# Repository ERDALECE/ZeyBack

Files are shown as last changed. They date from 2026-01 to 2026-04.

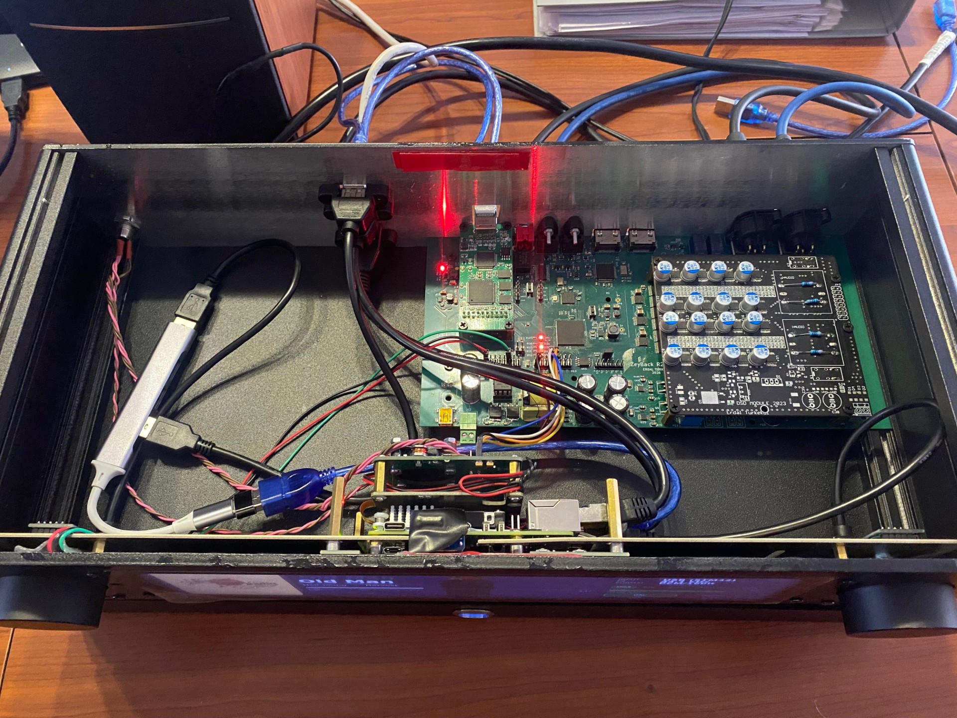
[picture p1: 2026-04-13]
Pictures/res5.jpg

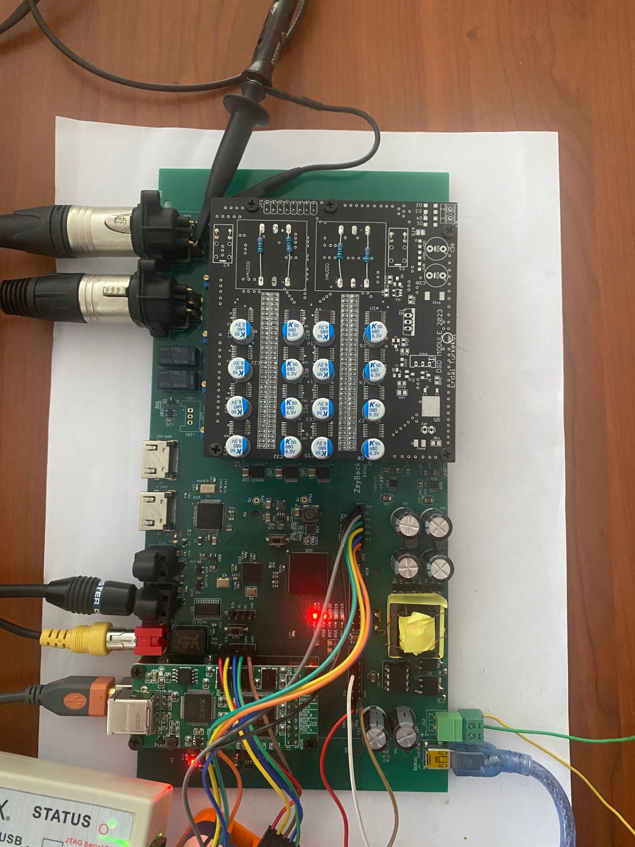
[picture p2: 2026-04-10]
Pictures/res1.jpg

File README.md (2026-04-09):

# ZeyBack R2RDAC

High-performance DIY USB Audio / FPGA based R-2R DAC platform.

The STM32H750 MCU plays audio in 44.1 kHz - 768 kHz PCM and DSD64 - DSD512 DSD (DoP) formats. 

Optionally, a second USB audio input can be added by connecting an XMOS or AMANERO.

SPDIF audio input up to 192 kHz is possible via the CS8416 or directly through the FPGA input.

It has one coaxial and two optical inputs.

HDMI audio input is possible with the ADV7611.

Direct I2S signal pins are also provided. An external I2S signal can also be supplied as an input through these pins.

With the SI5340, the reclocking operation is performed within the FPGA.

Input selection via infrared remote control is possible using the RC5 code. Debugging can be done via a separate USB COM port. 
Status information (sample rate, bitrate, selected input, etc.) is output as SPI from the FPGA.
MCUs, displays, etc., can be connected to SPI pins to display information via a GUI.

Main PCB is 6 Layer, DSD PCB is 4 Layer. 

All tests have been completed and no serious bugs have been found. However, it is open to improvement.

This repository contains:
- STM32H750 USB Audio Class 2.0 (UAC2) firmware (PCM + DSD related work)
- FPGA logic used for audio data path / clocking / I2S/DSD processing
- Hardware design files (KiCad schematics/PCB, BOM, Gerbers)

## Repository structure

- `Firmware/Stm32/`  
  STM32H750 project (STM32CubeIDE). Includes STM32Cube/HAL and middleware components.

- `Firmware/Fpga/`  
  FPGA project files (Vivado project + sources).

- `Hardware/`  
  KiCad project files, BOM/CSV, and manufacturing outputs (Gerbers).
  
- `Pictures/` 
  Some testing and pcb pictures.

## Build / Tools

- STM32: STM32CubeIDE (or gcc-arm + Make/CMake if you prefer)
- FPGA: Xilinx Vivado
- Hardware: KiCad

## DSD Native / Volumio notes

Goal: DSD Native playback on Linux (Volumio / Raspberry Pi) with proper USB descriptors and, if required,
a targeted `snd-usb-audio` quirk limited to this device (VID+PID).

## Licensing (IMPORTANT)

This repository is **multi-licensed**:

- **Firmware** (our original code): **GPL-3.0-or-later**
- **Hardware design files** (KiCad schematics/PCB): **CERN-OHL-S-2.0**
- **Documentation** (if/when added under `docs/`): **CC BY-SA 4.0**
- **Third-party components** (e.g., STM32Cube/HAL, middleware): keep their **original licenses**
  as stated in file headers and vendor license texts.

See:
- `LICENSE` (GPLv3 for the main project codebase)
- `Firmware/LICENSE` (firmware scope)
- `Hardware/LICENSE` (hardware scope)
- `THIRD_PARTY_NOTICES.md`

## Status

Work in progress....
Hardware design files in this directory (KiCad schematics/PCB and related design sources)
are licensed under CERN-OHL-S-2.0 (Strongly Reciprocal).

Manufacturing outputs (Gerbers) are provided for convenience.

See THIRD_PARTY_NOTICES.md for any third-party footprints/symbols (if applicable).

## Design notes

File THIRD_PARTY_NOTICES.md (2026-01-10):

# Third Party Notices

This repository may include third-party components such as:

## STM32Cube / ST HAL & Middleware
Files under `Firmware/Stm32/Drivers/` and parts of `Firmware/Stm32/Middlewares/` are provided by STMicroelectronics
and are distributed under their respective licenses.

- Do not remove or alter license headers in these files.
- These components remain under their original license terms.

## Other third-party content
If any additional third-party IP, HDL cores, footprints/symbols, or libraries are added,
they must retain their original license and be listed here.

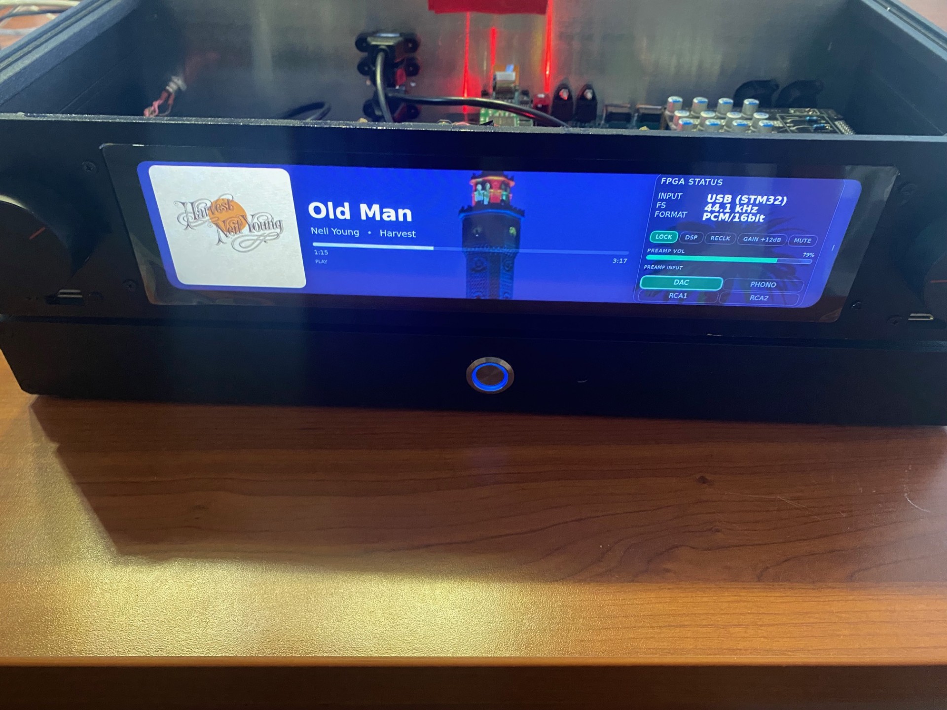
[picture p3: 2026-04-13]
Pictures/res4.jpg

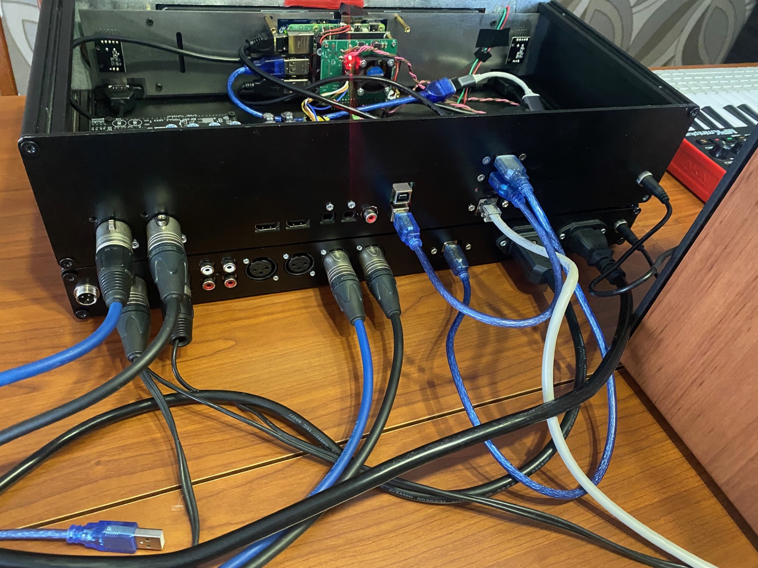
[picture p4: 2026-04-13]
Pictures/res8.jpg

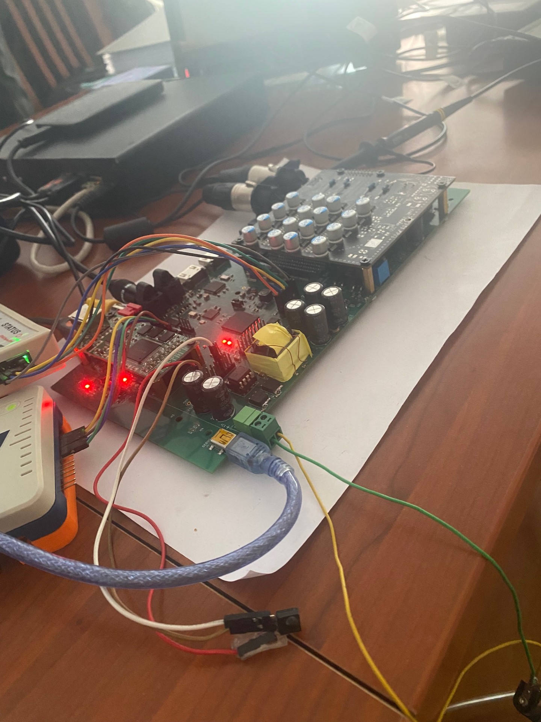
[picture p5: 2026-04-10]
Pictures/res2.jpg

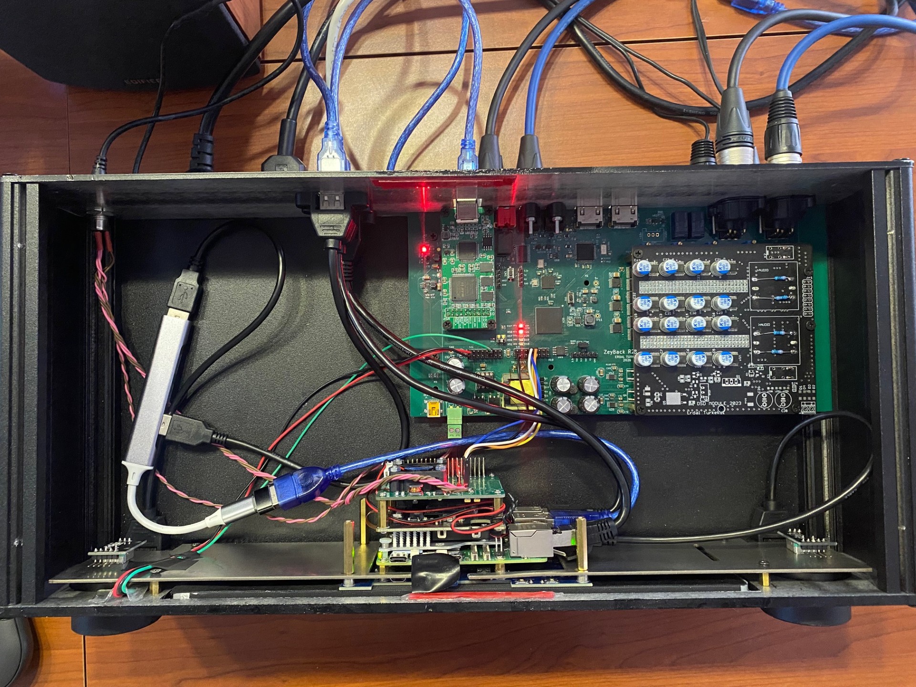
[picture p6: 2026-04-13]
Pictures/res6.jpg

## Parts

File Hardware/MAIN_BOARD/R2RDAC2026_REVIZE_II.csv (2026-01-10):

Source: | E:\KiCad Dosyalar\R2RDAC2025\R2RDAC2025.kicad_sch
Date: | Sun Feb 16 16:23:24 2025
Tool: | Eeschema 7.0.7
Generator: | C:\Program Files\KiCad\7.0\bin\scripting\plugins/bom_csv_grouped_by_value_with_fp.py
Component Count: | 797
Ref | Qnty | Value | Cmp name | Footprint | Description | Vendor | DNP
C1, C2, C3, C4, C5, C6, C8, C9, C10, C11, C14, C15, C16, C17, C18, C19, C20, C22, C40, C41, C42, C43, C44, C45, C46, C47, C48, C49, C50, C51, C76, C77, C78, C79, C119, C120, C166, C167, C170, C171, C172, C176, C177, C178, C179, C180, C181 | 47 | 100nf | C_0603 | XC7K325T_Footprint:C_0603_1608Metric | SMD 0603 MLCC capacitor, Alternate KiCad Library
C7, C23, C27, C29 | 4 | 10uf/6.3 | CP_SMD_Tantalum_Kemet-A_3216 | Capacitor_Tantalum_SMD:CP_EIA-3216-18_Kemet-A | SMD Tantalum Electrolytic Capacitor, Kemet Type A, 3216, US Symbol, Alternate KiCad Library
C12, C13 | 2 | 22pf | C_0603 | Capacitor_SMD:C_0603_1608Metric | SMD 0603 MLCC capacitor, Alternate KiCad Library
C21 | 1 | 1uf | C_0603 | XC7K325T_Footprint:C_0603_1608Metric | SMD 0603 MLCC capacitor, Alternate KiCad Library
C24, C75 | 2 | 10uF | C_0603 | PCM_Capacitor_SMD_AKL:C_0805_2012Metric | SMD 0603 MLCC capacitor, Alternate KiCad Library
C25, C34, C61, C62, C63, C185 | 6 | 100 nf | C_0603 | EP4CE_Footprint:C_0603_1608Metric | SMD 0603 MLCC capacitor, Alternate KiCad Library
C31, C32, C182, C183 | 4 | 4,7uF/16 | CP_SMD_Tantalum_Kemet-A_3216 | PCM_Capacitor_Tantalum_SMD_AKL:CP_EIA-3528-21_Kemet-B | SMD Tantalum Electrolytic Capacitor, Kemet Type A, 3216, European Symbol, Alternate KiCad Library
C33, C184 | 2 | 10 nf | C_0603 | EP4CE_Footprint:C_0603_1608Metric | SMD 0603 MLCC capacitor, Alternate KiCad Library
C35, C186 | 2 | 2,2nf | C_0603 | PCM_Capacitor_SMD_AKL:C_0603_1608Metric | SMD 0603 MLCC capacitor, Alternate KiCad Library
C36, C187 | 2 | 22pf | C_0603 | PCM_Capacitor_SMD_AKL:C_0603_1608Metric | SMD 0603 MLCC capacitor, Alternate KiCad Library
C37, C38, C188, C189 | 4 | 47uf/6.3 | CP_SMD_Tantalum_Kemet-B_3528 | PCM_Capacitor_Tantalum_SMD_AKL:CP_EIA-3216-18_Kemet-A | SMD Tantalum Electrolytic Capacitor, Kemet Type B, 3528, European Symbol, Alternate KiCad Library
C39, C190 | 2 | C_0603 | C_0603 | PCM_Capacitor_SMD_AKL:C_0603_1608Metric | SMD 0603 MLCC capacitor, Alternate KiCad Library
C52, C53 | 2 | CP_Radial_D8.0mm_P2.50mm | CP_Radial_D8.0mm_P2.50mm | PCM_Capacitor_THT_AKL:CP_Radial_D10.0mm_P7.50mm | THT Electrolytic Capacitor, 8.0mm Diameter, 2.50mm Pitch, European Symbol, Alternate KiCad Library
C54 | 1 | 470pf | C_0603 | PCM_Capacitor_SMD_AKL:C_0603_1608Metric | SMD 0603 MLCC capacitor, Alternate KiCad Library
C55, C56 | 2 | 10nf | C_0603 | PCM_Capacitor_SMD_AKL:C_0603_1608Metric | SMD 0603 MLCC capacitor, Alternate KiCad Library
C57, C58, C59, C60 | 4 | 1000uf/10v | CP_Radial_D8.0mm_P2.50mm | PCM_Capacitor_THT_AKL:CP_Radial_D10.0mm_P5.00mm | THT Electrolytic Capacitor, 8.0mm Diameter, 2.50mm Pitch, European Symbol, Alternate KiCad Library
C64, C65 | 2 | 47uf/10v | C_0603 | PCM_Capacitor_SMD_AKL:C_1210_3225Metric | SMD 0603 MLCC capacitor, Alternate KiCad Library
C66, C67, C70, C71 | 4 | 4.7uf | C_0603 | EP4CE_Footprint:C_0603_1608Metric | SMD 0603 MLCC capacitor, Alternate KiCad Library
C68, C69, C72, C73 | 4 | 10uf | C_0603 | PCM_Capacitor_SMD_AKL:C_0805_2012Metric | SMD 0603 MLCC capacitor, Alternate KiCad Library
C74, C84, C85, C86, C87, C88, C89, C90, C91, C92, C93, C94, C95, C96, C97, C98, C99, C100, C101, C102, C103, C104, C105, C106, C107, C108, C109, C110, C111, C112, C113, C114, C115, C116, C117, C118, C168, C169 | 38 | 100uf | C_0603 | PCM_Capacitor_SMD_AKL:C_1206_3216Metric | SMD 0603 MLCC capacitor, Alternate KiCad Library
C80, C81, C82, C83 | 4 | 100 pf | C_0603 | EP4CE_Footprint:C_0603_1608Metric | SMD 0603 MLCC capacitor, Alternate KiCad Library
C121, C122, C123, C124, C125, C127, C128, C129, C130, C131, C132, C133, C134, C135, C136, C137, C139, C140, C141, C142, C143, C144, C145, C146, C147, C148, C149, C151, C152, C153, C154, C155, C156, C157, C158, C159, C160, C162, C163, C164, C165 | 41 | 100nf | C_0603 | PCM_Capacitor_SMD_AKL:C_0603_1608Metric | SMD 0603 MLCC capacitor, Alternate KiCad Library
C126, C138, C150, C161 | 4 | 100uf | C_0603 | PCM_Capacitor_SMD_AKL:C_0603_1608Metric | SMD 0603 MLCC capacitor, Alternate KiCad Library
C173, C174, C175 | 3 | 2.2uf | C_0603 | PCM_Capacitor_SMD_AKL:C_0805_2012Metric | SMD 0603 MLCC capacitor, Alternate KiCad Library
D1, D11, D16 | 3 | DSS20-0015B | DSS20-0015B | Diode_SMD:D_SMA | TO-220 Schottky diode, 15V, 20A, Alternate KiCAD Library
D2, D12, D13, D14, D15 | 5 | RED | LTST-C150KRKT | LED_SMD:LED_0805_2012Metric | LED RED CLEAR 1206 SMD
D3, D4, D5, D6, D7, D8, D9, D10 | 8 | DSS20-0015B | DSS20-0015B | Diode_SMD:D_SOD-323_HandSoldering | TO-220 Schottky diode, 15V, 20A, Alternate KiCAD Library
H1, H2, H3, H4 | 4 | MountingHole | MountingHole | MountingHole:MountingHole_3.2mm_M3 | Mounting Hole without connection
H5, H6, H7, H8, H9, H10, H11, H12, H13, H14, H15, H16, H17, H18 | 14 | MountingHole | MountingHole | dac:MountingHole_3.2mm_M3 | Mounting Hole without connection
J1, J2 | 2 | NC3MBH-B | NC3MBH-B | Connector_Audio:Jack_XLR_Neutrik_NC3MBH-B_Horizontal | B Series, 3 pole male XLR receptacle, grounding: separate ground contact to mating connector shell and front panel, steel retention lug, horizontal PCB mount, black chrome shell
J3, J4 | 2 | Conn_02x24_Odd_Even | Conn_02x24_Odd_Even | Connector_PinHeader_2.00mm:PinHeader_2x24_P2.00mm_Vertical | Generic connector, double row, 02x24, odd/even pin numbering scheme (row 1 odd numbers, row 2 even numbers), script generated (kicad-library-utils/schlib/autogen/connector/)
J5 | 1 | XMOS | Conn_02x10_Odd_Even | Connector_PinHeader_2.54mm:PinHeader_2x10_P2.54mm_Vertical | Generic connector, double row, 02x10, odd/even pin numbering scheme (row 1 odd numbers, row 2 even numbers), script generated (kicad-library-utils/schlib/autogen/connector/)
J6 | 1 | USB_B | USB_B | dac:USB_B_Lumberg_2411_02_Horizontal | USB Type B connector
J7 | 1 | HDMI_A | HDMI_A | Connector_HDMI:HDMI_A_Molex_208658-1001_Horizontal | HDMI type A connector
J8 | 1 | HDMI_A | HDMI_A | XC7K325T_Footprint:HDMI_A_Molex_208658-1001_Horizontal | HDMI type A connector
J9 | 1 | Conn_01x05_Pin | Conn_01x05_Pin | Connector_PinHeader_2.54mm:PinHeader_1x05_P2.54mm_Vertical | Generic connector, single row, 01x05, script generated
J10, J11, J13 | 3 | Conn_02x08_Odd_Even | Conn_02x08_Odd_Even | Connector_PinHeader_2.54mm:PinHeader_2x08_P2.54mm_Vertical | Generic connector, double row, 02x08, odd/even pin numbering scheme (row 1 odd numbers, row 2 even numbers), script generated (kicad-library-utils/schlib/autogen/connector/)
J12 | 1 | Conn_01x02 | Conn_01x02 | Connector_Phoenix_MC:PhoenixContact_MCV_1,5_2-G-3.81_1x02_P3.81mm_Vertical | Generic connector, single row, 01x02, script generated (kicad-library-utils/schlib/autogen/connector/)
J14, J15 | 2 | 8P8C | 8P8C | dac:RJ45_OST_PJ012-8P8CX_Vertical | RJ connector, 8P8C (8 positions 8 connected), RJ31/RJ32/RJ33/RJ34/RJ35/RJ41/RJ45/RJ49/RJ61
J16 | 1 | Conn_01x04 | Conn_01x04 | Connector_PinHeader_2.54mm:PinHeader_1x04_P2.54mm_Vertical | Generic connector, single row, 01x04, script generated (kicad-library-utils/schlib/autogen/connector/)
J17 | 1 | Conn_01x02 | Conn_01x02 | Connector_PinHeader_2.54mm:PinHeader_1x02_P2.54mm_Vertical | Generic connector, single row, 01x02, script generated (kicad-library-utils/schlib/autogen/connector/)
JP1 | 1 | Jumper_3_Open | Jumper_3_Open | Jumper:SolderJumper-3_P1.3mm_Open_RoundedPad1.0x1.5mm_NumberLabels | Jumper, 3-pole, both open
L1 | 1 | 10 uH | L,IEC | Inductor_SMD:L_1008_2520Metric | coil/winding/inductor/choke/reactor (IEC)
L2, L3 | 2 | 47 uH | L,IEC | Inductor_SMD:L_1008_2520Metric | coil/winding/inductor/choke/reactor (IEC)
L4 | 1 | 3,3uH | 82103C | Inductor_SMD:L_Coilcraft_LPS3314 | FIXED IND 10UH 500MA 400 MOHM
L6, L9 | 2 | L | L | Inductor_SMD:L_7.3x7.3_H3.5 | coil/winding/inductor/choke/reactor
L7, L8 | 2 | 10uH | 82103C | Inductor_SMD:L_Coilcraft_LPS4018 | FIXED IND 10UH 500MA 400 MOHM
OPT1, OPT2 | 2 | TORX177 | TORX177 | dac:TORX177
Q1, Q2 | 2 | IRFR120N | IRFR120N | Package_TO_SOT_SMD:TO-252-2 | TO-252 N-MOSFET enchancement mode transistor, 100V, 9.4A, 48W, Alternate KiCAD Library
Q3, Q4 | 2 | MJD44H11 | MJD44H11 | PCM_Package_TO_SOT_SMD_AKL:TO-252-2 | NPN TO-252 power transistor, 80V, 8A, 20W, Alternate KiCAD Library
R1, R2, R3, R4, R5, R6, R7, R8, R16, R19, R21, R23, R25, R27, R29, R31, R33, R35, R37, R39, R41, R43, R45, R47, R49, R111, R112, R114, R116, R118, R120, R122, R124, R126, R128, R130, R132, R134, R136, R138, R140, R142, R144, R146, R148, R150, R152, R154, R156, R158, R164, R165, R166, R167, R170, R171, R174, R175, R178, R179, R182, R183, R186, R187, R190, R191, R194, R195, R198, R199, R202, R203, R206, R207, R210, R211, R214, R215, R218, R219, R222, R223, R226, R227, R230, R231, R234, R235, R238, R239, R242, R243, R246, R247, R250, R251, R254, R255, R258, R260 | 100 | 2R | R_0402 | PCM_Resistor_SMD_AKL:R_0603_1608Metric | SMD 0402 Chip Resistor, European Symbol, Alternate KiCad Library
R9, R10, R11, R12, R13, R14, R15, R17, R18, R20, R22, R24, R26, R28, R30, R32, R34, R36, R38, R40, R42, R44, R46, R48, R51, R113, R115, R117, R119, R121, R123, R125, R127, R129, R131, R133, R135, R137, R139, R141, R143, R145, R147, R149, R151, R153, R155, R157, R159, R160, R168, R169, R172, R173, R176, R177, R180, R181, R184, R185, R188, R189, R192, R193, R196, R197, R200, R201, R204, R205, R208, R209, R212, R213, R216, R217, R220, R221, R224, R225, R228, R229, R232, R233, R236, R237, R240, R241, R244, R245, R248, R249, R252, R253, R256, R257, R262, R263, R264, R265, R275, R276, R277, R278, R279, R280, R281, R282, R283, R284, R285, R286, R287, R288, R289, R290, R291, R292, R293, R294, R295, R296, R297, R298, R299, R300, R301, R302, R303, R304, R305, R306, R307, R308, R309, R310, R311, R312, R313, R314, R315, R316, R317, R318, R319, R320, R321, R322, R323, R324, R325, R326, R327, R328, R329, R330, R331, R332, R333, R334, R335, R336, R337, R338, R339, R340, R341, R342, R343, R344, R345, R346, R347, R348, R349, R350, R351, R352, R353, R354, R355, R356, R357, R358, R359, R360, R361, R362, R363, R364, R365, R366 | 192 | R | R_0402 | PCM_Resistor_SMD_AKL:R_0603_1608Metric | SMD 0402 Chip Resistor, European Symbol, Alternate KiCad Library
R50, R161, R266, R267, R367, R368, R369, R370, R371, R372, R373, R374, R375, R376, R377, R378, R379, R380, R381, R382, R383, R384, R385, R386, R387, R388, R389, R390, R391, R392, R393, R394, R395, R396, R397, R398, R399, R400, R401, R402, R403, R404, R405, R406, R407, R408, R409, R410, R411, R412, R413, R414, R415, R416, R417, R418, R419, R420, R421, R422, R423, R424, R425, R426, R427, R428, R429, R430, R431, R432, R433, R434, R435, R436, R437, R438, R439, R440, R441, R442, R443, R444, R445, R446, R447, R448, R449, R450, R451, R452, R453, R454, R455, R456, R457, R458 | 96 | VAR | R_0402 | PCM_Resistor_SMD_AKL:R_0603_1608Metric | SMD 0402 Chip Resistor, European Symbol, Alternate KiCad Library
R52, R53, R55, R57, R58, R59 | 6 | 4,7k | R_0603 | EP4CE_Footprint:R_0603_1608Metric | SMD 0603 Chip Resistor, European Symbol, Alternate KiCad Library
R54 | 1 | 390k | R_0603 | EP4CE_Footprint:R_0603_1608Metric | SMD 0603 Chip Resistor, European Symbol, Alternate KiCad Library
R56, R459 | 2 | 75 | R_0603 | EP4CE_Footprint:R_0603_1608Metric | SMD 0603 Chip Resistor, European Symbol, Alternate KiCad Library
R60, R61, R62, R63, R64, R65, R66, R67, R68, R69, R70, R71, R72, R73, R74, R75, R271, R272, R273 | 19 | 33 | R_0603 | EP4CE_Footprint:R_0603_1608Metric | SMD 0603 Chip Resistor, European Symbol, Alternate KiCad Library
R76 | 1 | 8.06k | R_0603 | EP4CE_Footprint:R_0603_1608Metric | SMD 0603 Chip Resistor, European Symbol, Alternate KiCad Library
R77, R80, R87, R90, R91, R92, R100, R105, R109, R274, R464 | 11 | 10k | R_0603 | EP4CE_Footprint:R_0603_1608Metric | SMD 0603 Chip Resistor, European Symbol, Alternate KiCad Library
R79 | 1 | 13,7k | R_0603 | EP4CE_Footprint:R_0603_1608Metric | SMD 0603 Chip Resistor, European Symbol, Alternate KiCad Library
R83, R460 | 2 | 665k | R_0603 | EP4CE_Footprint:R_0603_1608Metric | SMD 0603 Chip Resistor, European Symbol, Alternate KiCad Library
R84, R461 | 2 | 130k | R_0603 | EP4CE_Footprint:R_0603_1608Metric | SMD 0603 Chip Resistor, European Symbol, Alternate KiCad Library
R85, R462 | 2 | 37,4k | R_0603 | EP4CE_Footprint:R_0603_1608Metric | SMD 0603 Chip Resistor, European Symbol, Alternate KiCad Library
R86, R463 | 2 | R_0603 | R_0603 | PCM_Resistor_SMD_AKL:R_0603_1608Metric | SMD 0603 Chip Resistor, European Symbol, Alternate KiCad Library
R88, R465 | 2 | 2k | R_0603 | EP4CE_Footprint:R_0603_1608Metric | SMD 0603 Chip Resistor, European Symbol, Alternate KiCad Library
R89, R106, R107, R108, R268 | 5 | 1k | R_0603 | Capacitor_SMD:C_0603_1608Metric | SMD 0603 Chip Resistor, European Symbol, Alternate KiCad Library
R93, R98 | 2 | 750 | R_0603 | EP4CE_Footprint:R_0603_1608Metric | SMD 0603 Chip Resistor, European Symbol, Alternate KiCad Library
R94, R99 | 2 | 31k | R_0603 | EP4CE_Footprint:R_0603_1608Metric | SMD 0603 Chip Resistor, European Symbol, Alternate KiCad Library
R95, R96 | 2 | 10 | R_0603 | EP4CE_Footprint:R_0603_1608Metric | SMD 0603 Chip Resistor, European Symbol, Alternate KiCad Library
R97 | 1 | 15k | R_0603 | EP4CE_Footprint:R_0603_1608Metric | SMD 0603 Chip Resistor, European Symbol, Alternate KiCad Library
R101, R103 | 2 | 249k | R_0603 | EP4CE_Footprint:R_0603_1608Metric | SMD 0603 Chip Resistor, European Symbol, Alternate KiCad Library
R102, R104 | 2 | 49.9k | R_0603 | EP4CE_Footprint:R_0603_1608Metric | SMD 0603 Chip Resistor, European Symbol, Alternate KiCad Library
R110 | 1 | 100 | R_0603 | EP4CE_Footprint:R_0603_1608Metric | SMD 0603 Chip Resistor, European Symbol, Alternate KiCad Library
R162, R163, R259, R261 | 4 | 100 | R_0402 | PCM_Resistor_SMD_AKL:R_0603_1608Metric | SMD 0402 Chip Resistor, European Symbol, Alternate KiCad Library
R269 | 1 | 1m | R_0603 | Capacitor_SMD:C_0603_1608Metric | SMD 0603 Chip Resistor, European Symbol, Alternate KiCad Library
R270 | 1 | 0 | R_0603 | EP4CE_Footprint:R_0603_1608Metric | SMD 0603 Chip Resistor, European Symbol, Alternate KiCad Library
RCA1 | 1 | RCA | RCA | dac:RCA
RV1, RV2, RV3, RV4 | 4 | R_Potentiometer_Trim | R_Potentiometer_Trim | Potentiometer_THT:Potentiometer_Bourns_3296W_Vertical | Trim-potentiometer
RV5, RV6 | 2 | 2.2k | R_Potentiometer_Trim | Potentiometer_THT:Potentiometer_Bourns_3296W_Vertical | Trim-potentiometer
SW1 | 1 | SW_Push | SW_Push | Button_Switch_SMD:SW_SPST_CK_RS282G05A3 | Push button switch, generic, two pins
T1 | 1 | Transformer_1P_2S | TRANSF6 | Transformer:EE2006
TP1, TP2, TP3, TP4, TP5, TP6, TP7, TP8, TP9, TP10 | 10 | TestPoint | TestPoint | TestPoint:TestPoint_Pad_D2.0mm | test point
TRF1 | 1 | DIGITALTRAFO | DIGITALTRAFO | dac:DIGITALTRAFO
U1 | 1 | STM32F446VETx | STM32F446VETx | Package_QFP:LQFP-100_14x14mm_P0.5mm | STMicroelectronics Arm Cortex-M4 MCU, 512KB flash, 128KB RAM, 180 MHz, 1.8-3.6V, 81 GPIO, LQFP100
U2, U6, U9, U30, U33, U36, U43, U44, U49, U50, U55, U56 | 12 | 74LS595 | 74LS595 | LVC595:TSSOP16_SOT403-1_NXP_NEX | 8-bit serial in/out Shift Register 3-State Outputs
U3, U4, U5, U7, U8, U10, U29, U31, U32, U34, U35, U37, U41, U42, U45, U46, U47, U48, U51, U52, U53, U54, U57, U58 | 24 | SN74LVC245AN | SN74LVC245AN | Package_SO:TSSOP-20_4.4x6.5mm_P0.65mm | IC TXRX NON-INVERT 3.6V 20DIP
U11, U27, U28, U38, U39, U40, U59, U60 | 8 | SN74LVC1G04DBVR | SN74LVC1G04DBVR | dac:SOT-753 | IC INVERTER 1CH 1-INP SOT23-5
U12, U13 | 2 | LT3045xMSE | LT3045xMSE | Package_SO:MSOP-12-1EP_3x4mm_P0.65mm_EP1.65x2.85mm | 500mA, Adjustable, Ultralow Noise, Ultrahigh PSRR Linear Regulator, MSOP-12
U14 | 1 | USB3320C-EZK | USB3320C-EZK | XC7K325T_Footprint:QFN32_5X5MC_MCH
U15 | 1 | ADV7611BSWZ | ADV7611BSWZ | XC7K325T_Footprint:SW_64_2_ADI
U16, U17, U18 | 3 | SI8660BC-B-IS1R | SI8660BC-B-IS1R | SOIC16:SOIC16_SI823_SKY
U19 | 1 | IR2153 | IR2153 | PCM_Package_DIP_AKL:DIP-8_W7.62mm_Socket | Self-Oscillating Half-Bridge Driver, 600V, PDIP-8/SOIC-8
U20 | 1 | 74LVC1G3157 | 74LVC1G3157 | Package_TO_SOT_SMD:SOT-23-6_Handsoldering | SPDT Analog Switch, Low-Voltage CMOS
U21 | 1 | WM8805GEDS/RV | WM8805GEDS_RV | dac:SSOP28_10P2X5P3X1P75_CIR
U22, U23 | 2 | SN74LVC1G125DBVR | SN74LVC1G125DBVR | Package_TO_SOT_SMD:SOT-23-5 | IC BUF NON-INVERT 5.5V SOT23-5
U24 | 1 | TPS562201DDCR | TPS562201DDCR | TPS562201DDRC:DDC0006A_N
U26, U61 | 2 | TPS54531DDA | TPS54531DDA | EP4CE_Footprint:DDA8_3P1X2P4_TEX
X1 | 1 | 28.63636 mhz | X-crystal | Crystal:Crystal_SMD_5032-2Pin_5.0x3.2mm | piezoelectric crystal; xtal
X2 | 1 | 24.576 mhz | SG-5032CAN | Oscillator:Oscillator_SMD_SeikoEpson_SG8002LB-4Pin_5.0x3.2mm | CMOS Clock Oscillator 1 to 75 MHz

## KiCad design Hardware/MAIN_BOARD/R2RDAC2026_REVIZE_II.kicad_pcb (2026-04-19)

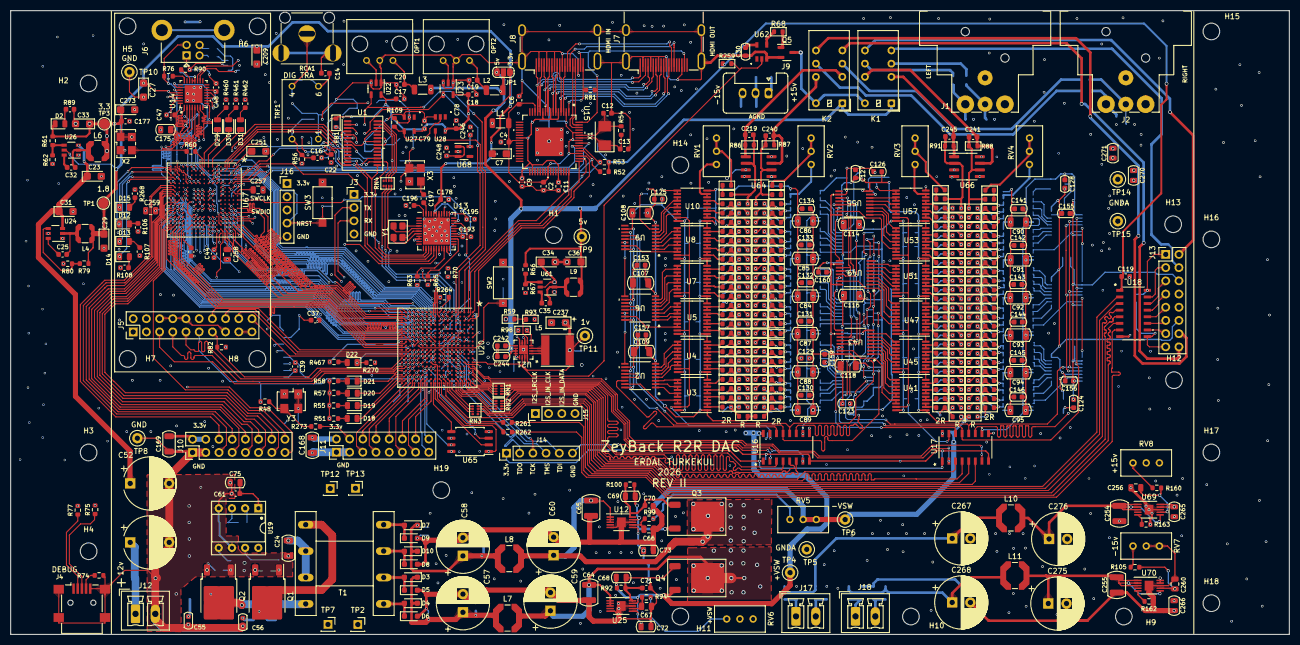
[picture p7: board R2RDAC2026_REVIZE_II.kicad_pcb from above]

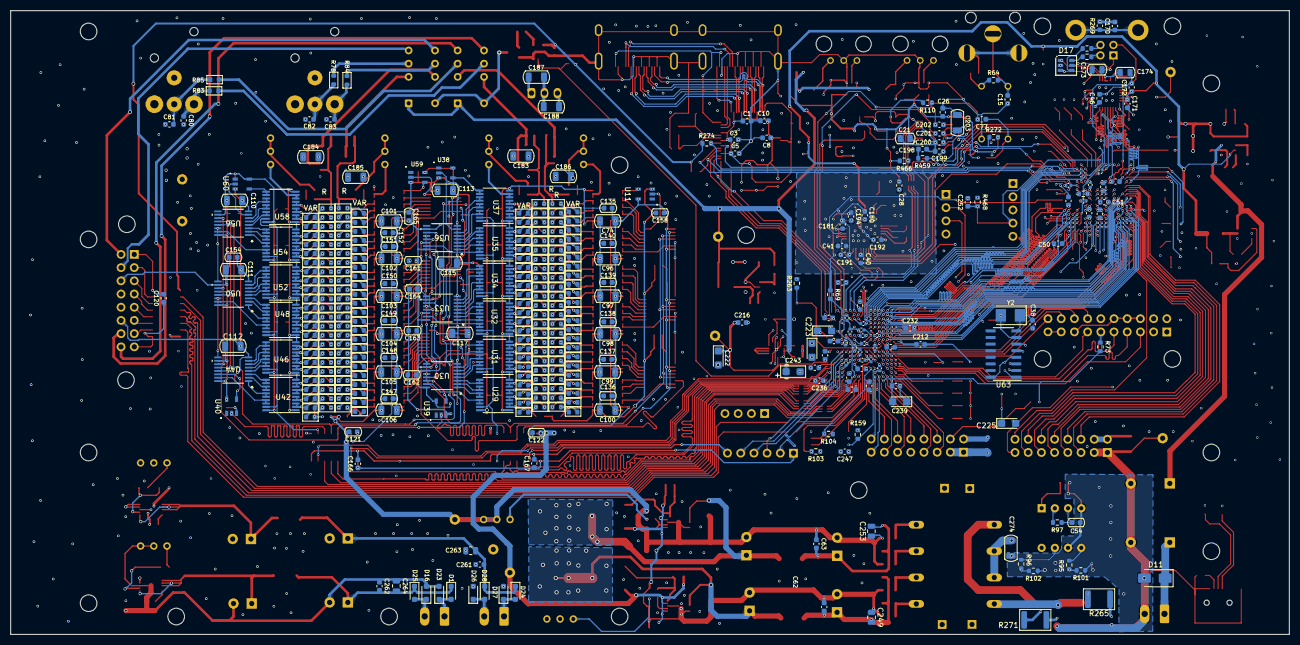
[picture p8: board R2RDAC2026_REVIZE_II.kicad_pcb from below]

Board: 6 copper layers, 246.0 x 120.0 mm, 940 parts (390 on the bottom side), 793 nets.

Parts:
C1, C2, C3, C4, C5, C6, C8, C9, C10, C11, C14, C15, C17, C18, C22, C26, C28, C30, C40, C41, C42, C43, C44, C46, C47, C48, C49, C50, C51, C78, C79, C119, C120, C121, C122, C123, C124, C125, C127, C128, C129, C130, C131, C132, C133, C134, C135, C136, C137, C139, C140, C141, C142, C143, C144, C145, C146, C147, C148, C149, C151, C152, C153, C154, C155, C156, C157, C158, C159, C160, C162, C163, C164, C165, C166, C167, C171, C172, C176, C177, C178, C180, C181, C191, C192, C193, C194, C195, C196, C197, C206, C221, C244, C250, C252: 100nf; C_0603_1608Metric
C7, C23, C27, C29, C33, C36, C209, C222, C223, C224, C225, C239, C251, C273: 10uf/6.3; CP_EIA-3216-18_Kemet-A
C12, C13: 22pf; C_0603_1608Metric
C16, C55, C56, C77: 10nf; C_0603_1608Metric
C19, C20: 1 uf; C_0603_1608Metric
C21: 1uf; C_0805_2012Metric
C24, C274: 10uF; C_1206_3216Metric
C25, C32, C35, C61, C62, C63, C179, C207, C212, C216, C226, C227, C229, C230, C231, C232, C233, C234, C235, C236, C238, C247, C261, C262: 100 nf; C_0603_1608Metric
C31, C34: 10uf/16v; CP_EIA-3216-18_Kemet-A
C37, C38: 22 pf; C_0603_1608Metric
C39, C200, C201, C202: 10 nf; C_0603_1608Metric
C45, C76, C189, C190, C204, C205, C208, C213, C214, C215, C217, C218, C220, C228, C272: 100 nf; C_0402_1005Metric
C52, C53: CP_Radial_D8.0mm_P2.50mm; CP_Radial_D10.0mm_P7.50mm
C54: 470pf; C_0603_1608Metric
C57, C58, C59, C60: 1000uf/10v; CP_Radial_D10.0mm_P3.50mm
C64, C65, C254, C255: 47uf/10v; C_1210_3225Metric
C66, C67, C256, C260: 4.7uf; C_0805_2012Metric
C68, C69, C72, C73, C265, C266, C270, C271: 10uf; C_0805_2012Metric
C70, C71, C246, C248: 4.7uf; C_0603_1608Metric
C74, C84, C85, C86, C87, C88, C89, C90, C91, C92, C93, C94, C95, C96, C97, C98, C99, C100, C101, C102, C103, C104, C105, C106, C107, C108, C109, C110, C111, C112, C113, C114, C115, C116, C117, C118, C168, C169, C183, C184, C185, C186, C187, C188, C203: 100uf; C_1206_3216Metric
C75: 10uF; C_0805_2012Metric
C80, C81, C82, C83, C219, C240, C241, C245: 100 pf; C_0603_1608Metric
C126, C138, C150, C161: 100uf; C_0603_1608Metric
C170, C199: 1 nf; C_0603_1608Metric
C173, C174, C175: 2.2uf; C_0805_2012Metric
C182, C210, C211, C269: 100nf; C_0402_1005Metric
C198: 22 nf; C_0603_1608Metric
C237: 47uf/6.3; CP_EIA-3216-18_Kemet-A
C242: 3.3nf; C_0603_1608Metric
C243: 4,7uF/16; CP_EIA-3216-18_Kemet-A
C249, C257, C258, C259, C263: 1 uf; C_0805_2012Metric
C253, C264: 1 uF; C_0805_2012Metric
C267, C268, C275, C276: 470uf/16v; CP_Radial_D10.0mm_P3.50mm
D1, D3, D4, D5, D6, D7, D8, D9, D10, D16, D23, D24, D25, D26, D27, D28: DSS20-0015B; D_SOD-323_HandSoldering
D2, D12, D13, D14, D15, D18, D19, D20, D21, D22, D29, D30, D31: RED; LED_0805_2012Metric
D11: DSS20-0015B; D_SMA
D17: USBLC6-2SC6; SOT-23-6
FB1: FerriteBead_Small; R_0603_1608Metric
H1, H2, H3, H4, H5, H6, H7, H8, H9, H10, H11, H12, H13, H14, H15, H16, H17, H18, H19: MountingHole; MountingHole_3.2mm_M3
J1, J2: NC3MBH-B; Jack_XLR_Neutrik_NC3MBH-B_Horizontal
J3: Conn_01x04; PinHeader_1x04_P2.54mm_Vertical
J4: USB_B_Micro; USB_Mini-B_Lumberg_2486_01_Horizontal
J5: XMOS; PinHeader_2x10_P2.54mm_Vertical
J6: USB_B; USB_B_Lumberg_2411_02_Horizontal
J7, J8: HDMI_A; HDMI_A_Molex_208658-1001_Horizontal
J9: Conn_01x03_Pin; Stocko_MKS_1653-6-0-303_1x3_P2.50mm_Vertical
J10, J11, J13: Conn_02x08_Odd_Even; PinHeader_2x08_P2.54mm_Vertical
J12, J17, J18: Conn_01x02; PhoenixContact_MCV_1,5_2-G-3.81_1x02_P3.81mm_Vertical
J14: Conn_01x06; PinHeader_1x06_P2.54mm_Vertical
J15: Conn_01x04_Pin; PinHeader_1x04_P2.54mm_Vertical
J16: Conn_01x05; PinHeader_1x05_P2.54mm_Vertical
JP1: Jumper_3_Open; SolderJumper-3_P1.3mm_Open_RoundedPad1.0x1.5mm_NumberLabels
K1, K2: EC2-5NU; Relay_DPDT_Kemet_EC2
L1: 10 uH; L_1206_3216Metric
L2, L3: 1 uH; L_1206_3216Metric
L4, L9: 2,2uH; L_Coilcraft_LPS3314
L5: 2.2uh; L_Taiyo-Yuden_NR-60xx
L6: 3,3uH; L_Coilcraft_LPS4018
L7, L8, L10, L11: 10uH; L_Coilcraft_LPS5030
OPT1, OPT2: TORX177
Q1, Q2: IRFR120N; TO-252-2
Q3, Q4: MJD44H11; TO-252-2
Q5: BC847; SOT-23-3
R1, R2, R3, R4, R5, R6, R7, R8, R16, R19, R21, R23, R25, R27, R29, R31, R33, R35, R37, R39, R41, R43, R45, R47, R49, R111, R112, R114, R116, R118, R120, R122, R124, R126, R128, R130, R132, R134, R136, R138, R140, R142, R144, R146, R148, R150, R152, R154, R156, R158, R164, R165, R166, R167, R170, R171, R174, R175, R178, R179, R182, R183, R186, R187, R190, R191, R194, R195, R198, R199, R202, R203, R206, R207, R210, R211, R214, R215, R218, R219, R222, R223, R226, R227, R230, R231, R234, R235, R238, R239, R242, R243, R246, R247, R250, R251, R254, R255, R258, R260: 2R; R_0603_1608Metric
R9, R10, R11, R12, R13, R14, R15, R17, R18, R20, R22, R24, R26, R28, R30, R32, R34, R36, R38, R40, R42, R44, R46, R113, R115, R117, R119, R121, R123, R125, R127, R129, R131, R133, R135, R137, R139, R141, R143, R145, R147, R149, R151, R153, R155, R157, R168, R169, R172, R173, R176, R177, R180, R181, R184, R185, R188, R189, R192, R193, R196, R197, R200, R201, R204, R205, R208, R209, R212, R213, R216, R217, R220, R221, R224, R225, R228, R229, R232, R233, R236, R237, R240, R241, R244, R245, R248, R249, R252, R253, R256, R257, R275, R276, R277, R278, R279, R280, R281, R282, R283, R284, R285, R286, R287, R288, R289, R290, R291, R292, R293, R294, R295, R296, R297, R298, R299, R300, R301, R302, R303, R304, R305, R306, R307, R308, R309, R310, R311, R312, R313, R314, R315, R316, R317, R318, R319, R320, R321, R322, R323, R324, R325, R326, R327, R328, R329, R330, R331, R332, R333, R334, R335, R336, R337, R338, R339, R340, R341, R342, R343, R344, R345, R346, R347, R348, R349, R350, R351, R352, R353, R354, R355, R356, R357, R358, R359, R360, R361, R362, R363, R364, R365, R366: R; R_0603_1608Metric
R48, R60, R73, R273: 33; R_0603_1608Metric
R50, R161, R266, R267, R367, R368, R369, R370, R371, R372, R373, R374, R375, R376, R377, R378, R379, R380, R381, R382, R383, R384, R385, R386, R387, R388, R389, R390, R391, R392, R393, R394, R395, R396, R397, R398, R399, R400, R401, R402, R403, R404, R405, R406, R407, R408, R409, R410, R411, R412, R413, R414, R415, R416, R417, R418, R419, R420, R421, R422, R423, R424, R425, R426, R427, R428, R429, R430, R431, R432, R433, R434, R435, R436, R437, R438, R439, R440, R441, R442, R443, R444, R445, R446, R447, R448, R449, R450, R451, R452, R453, R454, R455, R456, R457, R458: VAR; R_0603_1608Metric
R51, R55, R57, R58, R68, R162, R163, R263, R270, R467: 1k; R_0603_1608Metric
R52, R53, R81, R82, R272, R466: 4,7k; R_0603_1608Metric
R54: 390k; R_0603_1608Metric
R56, R64: 75; R_0603_1608Metric
R59: 51k; R_0603_1608Metric
R61: 22.1k; R_0603_1608Metric
R62, R98: 100k; R_0603_1608Metric
R63, R65, R69, R70, R71, R72, R261, R262: 22; R_0603_1608Metric
R66: 54.9k; R_0603_1608Metric
R67, R80, R90, R92, R100, R109, R259, R274, R468, R470: 10k; R_0603_1608Metric
R74: 1,5k; R_0603_1608Metric
R75, R77: 27; R_0603_1608Metric
R76: 8.06k; R_0603_1608Metric
R78, R83, R84, R85, R86, R87, R88, R91, R110: 100; R_0603_1608Metric
R79: 13,7k; R_0603_1608Metric
R89, R106, R107, R108, R268, R460, R461, R462: 1k; C_0603_1608Metric
R93: 200k; R_0603_1608Metric
R94, R99, R105, R160: 31k; R_0603_1608Metric
R95, R96: 10; R_0603_1608Metric
R97: 15k; R_0603_1608Metric
R101, R102: 47k; R_0603_1608Metric
R103, R104, R159, R264: 4.7k; R_0603_1608Metric
R265, R271: 10; R_1812_4532Metric
R269: 1m; C_0603_1608Metric
R459: 3k; R_0603_1608Metric
RCA1: RCA
RN1, RN2, RN3, RN4: R_4x0402_Convex; R_Array_Convex_4x0402
RV1, RV2, RV3, RV4: 50; Potentiometer_Bourns_3296W_Vertical
RV5, RV6, RV7, RV8: 2.2k; Potentiometer_Bourns_3296W_Vertical
SW2, SW3: SW_Push; SW_SPST_CK_RS282G05A3
T1: Transformer_1P_2S; EE2006
TP1, TP3: TestPoint; TestPoint_Pad_D2.0mm
TP2, TP7, TP12, TP13: TestPoint; PinSocket_1x01_P2.54mm_Vertical
TP4, TP5, TP6, TP8, TP9, TP10, TP14, TP15: TestPoint; TestPoint_Loop_D2.50mm_Drill1.0mm
TP11: 1v; TestPoint_Loop_D2.50mm_Drill1.0mm
TRF1: DIGITALTRAFO
U1: CS8416-xZZ; TSSOP-28_4.4x9.7mm_P0.65mm
U2, U6, U9, U30, U33, U36, U43, U44, U49, U50, U55, U56: 74LS595; TSSOP16_SOT403-1_NXP_NEX
U3, U4, U5, U7, U8, U10, U29, U31, U32, U34, U35, U37, U41, U42, U45, U46, U47, U48, U51, U52, U53, U54, U57, U58: SN74LVC245AN; TSSOP-20_4.4x6.5mm_P0.65mm
U11, U27, U28, U38, U39, U40, U59, U60, U62: SN74LVC1G04DBVR; SOT-753
U12, U25, U69, U70: LT3042xMSE; MSOP-10-1EP_3x3mm_P0.5mm_EP1.68x1.88mm
U13: Si5342A-D; QFN-44-1EP_7x7mm_P0.5mm_EP5.2x5.2mm
U14: USB3320C-EZK; QFN32_5X5MC_MCH
U15: ADV7611BSWZ; SW_64_2_ADI
U16, U17, U18: SI8660BC-B-IS1R; SOIC16_SI823_SKY
U19: IR2153; DIP-8_W7.62mm_Socket
U20: XC7A100T-CSG324; BGA-324_15.0x15.0mm_Layout18x18_P0.8mm_Ball0.45mm_Pad0.4mm_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
U21: TPS62130RGTT; TPS62130
U22, U23: SN74LVC1G125DBVR; SOT-23-5
U24, U26, U61: TPS562201DDCR; DDC0006A_N
U63: CH340G; SOIC-16_3.9x9.9mm_P1.27mm
U64, U66: OPA2134UA; SOIC-8_3.9x4.9mm_P1.27mm
U65: W25Q128JVS; SOIC-8_5.23x5.23mm_P1.27mm
U67: STM32H750XBHx; TFBGA-265_14x14mm_Layout17x17_P0.8mm
U68: AP2127K-1.8; SOT-23-5
X1: 28.63636 mhz; Crystal_SMD_5032-2Pin_5.0x3.2mm
X2, X3: 24.576 mhz; Oscillator_SMD_SeikoEpson_SG8002LB-4Pin_5.0x3.2mm
Y1: Crystal_GND24; Crystal_SMD_3225-4Pin_3.2x2.5mm
Y2: 12 Mhz; Crystal_SMD_5032-2Pin_5.0x3.2mm
Y3: 50mhz; Oscillator_SMD_EuroQuartz_XO53-4Pin_5.0x3.2mm_HandSoldering

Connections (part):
1.8V_ENB: R98.2, U21.4 (PG), U24.5 (EN)
1.8v ADV: C246.1, L1.1 (+), U68.5 (VOUT)
24Mhz_ULPI: U14.26 (REFCLK), U67.E15 (PA8)
+1V0: C76.1, C190.1, C205.1, C213.1, C214.1, C215.1, C216.1, C217.1, C218.1, C220.1, C222.1, C223.1, C237.1, L5.1 (+), R59.1, TP11.1, U20.F8 (VCCINT), U20.F10 (VCCBRAM), U20.G7 (VCCINT), U20.G9 (VCCINT), U20.G11 (VCCBRAM), U20.H8 (VCCINT), U20.J7 (VCCINT), U20.J11 (VCCINT), U20.K8 (VCCINT), U20.L7 (VCCINT), U20.L11 (VCCINT), U20.M8 (VCCINT), U20.M10 (VCCINT), U20.N7 (VCCINT), U20.N9 (VCCINT), U20.N11 (VCCINT), U21.14 (VOS)
+1V8: C27.1, C29.1, C45.1, C171.1, C172.1, C178.1, C179.1, C180.1, C181.1, C191.1, C204.1, C207.1, C208.1, C209.1, L4.2, R79.1, TP1.1, U13.21 (VDD), U13.32 (VDD), U13.39 (VDD), U13.40 (VDD), U14.28 (VDD18), U14.30 (VDD18), U20.E8 (VCCBATT_0), U20.F12 (VCCAUX), U20.H10 (VCCADC_0), U20.H12 (VCCAUX), U20.K12 (VCCAUX), U20.M12 (VCCAUX), U26.5 (EN)
+3.3V: C8.1, C9.1, C10.1, C11.1, C17.1, C18.1, C21.2, C22.2, C26.2, C28.1, C30.1, C33.1, C39.1, C40.1, C41.1, C42.1, C43.1, C44.1, C46.1, C47.1, C48.1, C49.1, C50.1, C51.1, C78.1, C79.1, C119.1, C166.1, C167.1, C168.1, C169.1, C174.1, C175.2, C176.1, C177.1, C182.1, C189.1, C192.1, C193.1, C194.1, C195.1, C206.1, C210.1, C211.1, C212.1, C221.1, C224.1, C225.1, C226.1, C227.1, C228.1, C229.1, C230.1, C231.1, C232.1, C233.1, C234.1, C235.1, C236.1, C238.1, C239.1, C247.1, C248.1, C250.1, C251.1, C269.1, C272.1, C273.1, D2.1, FB1.1, J3.1, J10.2, J10.4, J11.2, J14.1, J16.1, JP1.3 (B), L6.2, R52.1, R53.2, R61.1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
+3.3VP: J5.17, J5.19
+5V: C36.1, C243.1, C244.1, JP1.1 (A), K1.1, K2.1, L9.2, R66.1, R98.1, TP9.1, U21.10 (AVIN), U21.11 (PVIN), U21.12 (PVIN), U21.13 (EN)
+12V: C23.1, C24.1, C31.1, C34.1, C52.1, C53.1, C61.2, C75.2, C274.1, D11.1 (K), J12.1, T1.2, T1.3, U19.1 (VCC), U19.8 (VB), U24.3 (VIN), U26.3 (VIN), U61.3 (VIN), U61.5 (EN)
+15V: C183.1, C184.1, C187.1, C265.1, C270.1, J9.1, U64.8 (V+), U66.8 (V+), U69.9 (OUTS), U69.10 (OUT)
+VSW: C68.2, C72.1, C74.1, C84.1, C85.1, C86.1, C87.1, C88.1, C89.1, C90.1, C91.1, C92.1, C93.1, C94.1, C95.1, C96.1, C97.1, C98.1, C99.1, C100.1, C101.1, C102.1, C103.1, C104.1, C105.1, C106.1, C107.1, C108.1, C109.1, C110.1, C111.1, C112.1, C113.1, C114.1, C115.1, C116.1, C117.1, C118.1, C121.1, C122.1, C123.1, C124.1, C125.1, C126.1, C127.1, C128.1, C129.1, C130.1, C131.1, C132.1, C133.1, C134.1, C135.1, C136.1, C137.1, C138.1, C139.1, C140.1, C141.1, C142.1, C143.1, C144.1, C145.1, C146.1, C147.1, C148.1, C149.1, C150.1, C151.1, C152.1, C153.1, C154.1, C155.1, C156.1, C157.1, C158.1, C159.1, C160.1, C161.1, C162.1, C163.1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
-15V: C185.1, C186.1, C188.1, C255.1, C260.2, C262.1, C264.1, C266.2, C268.2, C271.1, C275.2, D16.2 (A), D23.2 (A), J9.3, R162.1, RV7.1, RV7.2, U64.4 (V-), U66.4 (V-), U70.8 (GND), U70.11 (GND)
-VSW: C58.2, C60.2, C63.1, C65.1, C66.2, C70.2, C73.2, C74.2, C84.2, C85.2, C86.2, C87.2, C88.2, C89.2, C90.2, C91.2, C92.2, C93.2, C94.2, C95.2, C96.2, C97.2, C98.2, C99.2, C100.2, C101.2, C102.2, C103.2, C104.2, C105.2, C106.2, C107.2, C108.2, C109.2, C110.2, C111.2, C112.2, C113.2, C114.2, C115.2, C116.2, C117.2, C118.2, C121.2, C122.2, C123.2, C124.2, C125.2, C126.2, C127.2, C128.2, C129.2, C130.2, C131.2, C132.2, C133.2, C134.2, C135.2, C136.2, C137.2, C138.2, C139.2, C140.2, C141.2, C142.2, C143.2, C144.2, C145.2, C146.2, C147.2, C148.2, C149.2, C150.2, C151.2, C152.2, C153.2, C154.2, C155.2, C156.2, C157.2, C158.2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
A0: U20.M2 (IO_L4N_T0_34), U67.G4 (PF0)
A1: U20.K3 (IO_L2P_T0_34), U67.G3 (PF1)
BCLK_L: U2.11 (SRCLK), U6.11 (SRCLK), U9.11 (SRCLK), U16.13 (B3), U30.11 (SRCLK), U33.11 (SRCLK), U36.11 (SRCLK)
BCLK_L_F: RN1.3 (R3.1), U16.4 (A3)
BCLK_R: U17.13 (B3), U43.11 (SRCLK), U44.11 (SRCLK), U49.11 (SRCLK), U50.11 (SRCLK), U55.11 (SRCLK), U56.11 (SRCLK)
BCLK_R_F: RN2.3 (R3.1), U17.4 (A3)
CCLK: U20.E9 (CCLK_0), U65.6 (CLK)
CEC: J7.13 (CEC), J8.13 (CEC)
COAX: C16.2, U1.4 (RXP0)
COAX_FPGA_IN: C77.2, R110.1
COAX_FPGA_OUT: U20.E2 (IO_L14P_T2_SRCC_35), U28.4 (Y)
CSB: U1.14 (AD0/~CS/NV/RERR), U67.D2 (PE4)
CSB_SI: U13.16 (A0/~CS), U67.A3 (PI5)
CSO: R103.2, U20.L13 (IO_L6P_T0_FCS_B_14), U65.1 (~CS)
D0: U20.K17 (IO_L1P_T0_D00_MOSI_14), U65.5 (DI(IO0))
D1: U20.K18 (IO_L1N_T0_D01_DIN_14), U65.2 (DO(IO1))
D2: R104.2, U20.L14 (IO_L2P_T0_D02_14), U65.3 (IO2)
D3: R159.2, U20.M14 (IO_L2N_T0_D03_14), U65.7 (IO3)
D+: D17.3 (L2), U14.18 (DP)
D-: D17.1 (L1), U14.19 (DM)
DATA_N_L: U16.11 (B5), U39.2 (A)
DATA_N_L_F: RN1.1 (R1.1), U16.6 (A5)
DATA_N_R: U17.11 (B5), U40.2 (A)
DATA_N_R_F: RN2.1 (R1.1), U17.6 (A5)
DATA_P_L: U2.14 (SER), U16.14 (B2)
DATA_P_L_F: RN1.4 (R4.1), U16.3 (A2)
DATA_P_R: U17.14 (B2), U43.14 (SER)
DATA_P_R_F: RN2.4 (R4.1), U17.3 (A2)
DIR: U14.31 (DIR), U67.F4 (PI11)
DS0: U20.U7 (IO_L22P_T3_34), U67.P16 (PD14)
DS1: U20.P3 (IO_L14N_T2_SRCC_34), U67.P15 (PD15)
DS2: U20.R5 (IO_L19N_T3_VREF_34), U67.D13 (PD0)
DS3: U20.N2 (IO_L3P_T0_DQS_34), U67.E12 (PD1)
DS4: U20.R2 (IO_L15N_T2_DQS_34), U67.U9 (PE7)
DS5: U20.P2 (IO_L15P_T2_DQS_34), U67.T9 (PE8)
DS6: U20.T1 (IO_L17N_T2_34), U67.P9 (PE9)
DS7: U20.R1 (IO_L17P_T2_34), U67.N9 (PE10)
DS8: U20.U1 (IO_L7P_T1_34), U67.P10 (PE11)
DS9: U20.V1 (IO_L7N_T1_34), U67.R10 (PE12)
DS10: U20.R7 (IO_L23P_T3_34), U67.T10 (PE13)
DS11: U20.R8 (IO_L24P_T3_34), U67.U10 (PE14)
DS12: U20.T3 (IO_L11N_T1_SRCC_34), U67.R11 (PE15)
DS13: U20.U9 (IO_L21P_T3_DQS_34), U67.U16 (PD8)
DS14: U20.U8 (IO_25_34), U67.T17 (PD9)
DS15: U20.V9 (IO_L21N_T3_DQS_34), U67.T16 (PD10)
DS16: U20.N6 (IO_L18N_T2_34), U67.T13 (PH8)
DS17: U20.R6 (IO_L19P_T3_34), U67.R13 (PH9)
DS18: U20.P4 (IO_L14P_T2_SRCC_34), U67.P13 (PH10)
DS19: U20.R3 (IO_L11P_T1_SRCC_34), U67.P14 (PH11)
DS20: U20.T6 (IO_L23N_T3_34), U67.R14 (PH12)
DS21: U20.V6 (IO_L20N_T3_34), U67.D16 (PH13)
DS22: U20.U6 (IO_L22N_T3_34), U67.B17 (PH14)
DS23: U20.V5 (IO_L10P_T1_34), U67.B16 (PH15)
DS24: U20.V4 (IO_L10N_T1_34), U67.A16 (PI0)
DS25: U20.U3 (IO_L8N_T1_34), U67.A15 (PI1)
DS26: U20.U4 (IO_L8P_T1_34), U67.B15 (PI2)
DS27: U20.N4 (IO_L16N_T2_34), U67.C14 (PI3)
DS28: U20.M6 (IO_L18P_T2_34), U67.A2 (PI6)
DS29: U20.L3 (IO_L2N_T0_34), U67.B3 (PI7)
DS30: U20.L4 (IO_L5N_T0_34), U67.E2 (PI9)
DS31: U20.L1 (IO_L1P_T0_34), U67.F3 (PI10)
DSD_A: RN3.3 (R3.1), U18.3 (A2)
DSD_A_N: R261.2, U18.6 (A5)
DSD_B: RN3.2 (R2.1), U18.4 (A3)
DSD_B_N: R262.2, U18.7 (A6)
DSD_CLK: RN3.4 (R4.1), U18.2 (A1)
DSD_EN: U18.5 (A4), U20.H17 (IO_L18P_T2_A24_15)
DSD_EN_RL: R259.1, U20.A13 (IO_L9P_T1_DQS_AD3P_15), U62.2 (A)
DSD_ON: J5.13, R82.2, U20.V12 (IO_L20N_T3_A07_D23_14)
F0: J5.14, U20.V10 (IO_L21P_T3_DQS_14)
F1: J5.16, U20.T10 (IO_L24N_T3_A00_D16_14)
F2: J5.18, U20.V11 (IO_L21N_T3_DQS_A06_D22_14)
F3: J5.20, U20.U11 (IO_L19N_T3_A09_D25_VREF_14)
GND: C1.2, C2.2, C3.2, C4.2, C5.2, C6.2, C7.2, C8.2, C9.2, C10.2, C11.2, C12.2, C13.2, C15.1, C17.2, C18.2, C19.1, C20.1, C21.1, C22.1, C23.2, C24.2, C26.1, C27.2, C28.2, C29.2, C30.2, C31.2, C33.2, C34.2, C36.2, C37.1, C38.2, C39.2, C40.2, C41.2, C42.2, C43.2, C44.2, C45.2, C46.2, C47.2, C48.2, C49.2, C50.2, C51.2, C52.2, C53.2, C54.2, C55.2, C56.2, C61.1, C75.1, C76.2, C78.2, C79.2, C119.2, C166.2, C167.2, C168.2, C169.2, C170.2, C171.2, C172.2, C173.2, C174.2, C175.1, C176.2, C177.2, C178.2, C179.2, C180.2, C181.2, C182.2, C189.2, C190.2, C191.2, C192.2, C193.2, C194.2, C195.2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
GNDA: C57.2, C59.2, C62.1, C64.1, C67.2, C69.2, C71.2, C72.2, C73.1, C80.2, C81.1, C82.1, C83.2, C183.2, C184.2, C185.2, C186.2, C187.2, C188.2, C249.1, C254.1, C256.2, C261.1, C263.1, C265.2, C266.1, C267.2, C270.2, C271.2, C276.2, D5.2 (A), D6.2 (A), D26.2 (A), D27.2 (A), J1.1, J1.G, J2.1, J2.G, J9.2, J13.10, Q3.3 (E), R100.1, R163.1, RV6.1, RV6.2, RV8.1, RV8.2, TP5.1, TP14.1, TP15.1, U12.6 (PGFB), U12.9 (OUTS), U25.5 (ILIM), U25.8 (GND), U25.11 (GND), U64.3 (+), U64.5 (+), U66.3 (+), U66.5 (+), U69.8 (GND), U69.11 (GND), U70.9 (OUTS), U70.10 (OUT)
HDMI_I2S_BCLK: U15.49 (SCLK/INT2), U20.A1 (IO_L9N_T1_DQS_AD7N_35)
HDMI_I2S_DATA: U15.48 (AP), U20.B2 (IO_L10N_T1_AD15N_35)
HDMI_I2S_LRCLK: U15.50 (LRCLK), U20.B1 (IO_L9P_T1_DQS_AD7P_35)
HDMI_INDSCL: J8.15 (SCL), U15.62 (DDCA_SCL)
HDMI_INDSDA: J8.16 (SDA), U15.63 (DDCA_SDA)
HDMI_IN_5v: J7.18 (+5V), J8.18 (+5V), R81.1, U15.64 (RXA_5V)
HDMI_IN_INT1: U15.55 (INT1), U67.B4 (PE1)
HDMI_IN_MCLK: U15.51 (MCLK/INT2), U20.B3 (IO_L10P_T1_AD15P_35)
HDMI_IN_RESET: R274.2, U15.56 (*RESET), U67.A4 (PI4)
HDMI_IN_SCL: R52.2, U15.53 (SCL), U67.B5 (PB6)
HDMI_IN_SDA: R53.1, U15.54 (SDA), U67.C5 (PB7)
HPD: J8.19 (HPD), R81.2, U15.1 (HPA_A/INT2)
I2S_IN_CLK: J15.2, U20.D15 (IO_L12P_T1_MRCC_15)
I2S_IN_DATA: J15.3, U20.E16 (IO_L11N_T1_SRCC_15)
I2S_IN_LRCLK: J15.1, U20.E15 (IO_L11P_T1_SRCC_15)
IO0: J11.5, U20.U18 (IO_L17N_T2_A13_D29_14)
IO1: J11.6, U20.T18 (IO_L7N_T1_D10_14)
IO2: J11.7, U20.R17 (IO_L12N_T1_MRCC_14)
IO3: J11.8, U20.R18 (IO_L7P_T1_D09_14)
IO4: J11.9, U20.R16 (IO_L15P_T2_DQS_RDWR_B_14)
IO5: J11.10, U20.P18 (IO_L9N_T1_DQS_D13_14)
IO6: J11.11, U20.N17 (IO_L9P_T1_DQS_14)
IO7: J11.12, U20.M17 (IO_L10N_T1_D15_14)
IO8: J11.13, U20.M18 (IO_L4N_T0_D05_14)
IO9: J11.14, U20.L18 (IO_L4P_T0_D04_14)
IO10: J11.15, U20.N16 (IO_L11N_T1_SRCC_14)
IO11: J11.16, U20.M16 (IO_L10P_T1_D14_14)
IO12: J11.4, R273.2
IR: J10.12, U67.R9 (PF15)
LCLK: U2.12 (RCLK), U6.12 (RCLK), U9.12 (RCLK), U16.12 (B4), U30.12 (RCLK), U33.12 (RCLK), U36.12 (RCLK)
LCLK_F: RN1.2 (R2.1), U16.5 (A4)
LED1: D15.1, U67.U3 (PA4)
LED2: D12.1, U67.R3 (PA6)
LED3: D13.1, U67.T4 (PC4)
LED4: D14.1, U67.U4 (PC5)
LED5: D29.1, U67.J1 (PH1)
LED6: D30.1, U67.H1 (PI12)
LED7: D31.1, U67.G1 (PF2)
LEDF1: D21.1, U20.V16 (IO_L16N_T2_A15_D31_14)
LEDF2: D20.1, U20.U16 (IO_L18P_T2_A12_D28_14)
LEDF3: D19.1, U20.V17 (IO_L18N_T2_A11_D27_14)
LEDF4: D18.1, U20.U17 (IO_L17P_T2_A14_D30_14)
LEFT+: C219.2, R46.2, R47.2, R86.1, R297.2, U64.2 (-)
LEFT-: C240.2, R87.1, R157.2, R158.2, R320.2, U64.6 (-)
LEFT_OUT+: C240.1, K2.10, R87.2, U64.7
LEFT_OUT-: C219.1, K2.3, R86.2, U64.1
MCU_CLK: R60.2, X2.3 (OUT)
NE1: U20.N1 (IO_L3N_T0_DQS_34), U67.C11 (PD7)
NOE: U20.V2 (IO_L9N_T1_DQS_34), U67.A12 (PD4)
NRST: C252.1, J16.4, R468.2, SW3.1, U67.K1 (NRST)
NWAIT: U20.M1 (IO_L1N_T0_34), U67.B11 (PD6)
NWE: U20.U2 (IO_L9P_T1_DQS_34), U67.A11 (PD5)
NXT: U14.2 (NXT), U67.M4 (PC3)
unnamed: C14.1, RCA1.BREAK, RCA1.SPRING
unnamed: C14.2, R64.1, TRF1.6
unnamed: C15.2, R64.2, RCA1.BARREL, TRF1.4
unnamed: C16.1, C77.1, R56.1, TRF1.3
unnamed: C55.1, R265.1
unnamed: C56.1, R271.1
unnamed: C80.1, J2.2, R83.1
unnamed: C81.2, J2.3, R85.1
unnamed: C82.2, J1.3, R78.1
unnamed: C83.1, J1.2, R84.1
unnamed: C198.2, R459.2
unnamed: C257.1, U67.A7 (VCAP)
unnamed: C258.1, U67.D17 (VCAP)
unnamed: C259.1, U67.U11 (VCAP)
unnamed: D1.2 (A), D23.1 (K), J18.1, TP13.1
unnamed: C262.2, C264.2, C268.1, D1.1 (K), D25.1 (K), L11.1
unnamed: D2.2, R89.1
unnamed: D3.2 (A), D5.1 (K), T1.7
unnamed: C57.1, C62.2, C249.2, D3.1 (K), D4.1 (K), L7.1
unnamed: D4.2 (A), D6.1 (K), T1.8
unnamed: D7.2 (A), D9.1 (K), T1.5
unnamed: D8.1 (K), D10.2 (A), T1.6
unnamed: C58.1, C63.2, C253.2, D7.1 (K), D10.1 (K), L8.1
unnamed: D12.2, R106.1
unnamed: D13.2, R107.1
unnamed: D14.2, R108.1
unnamed: D15.2, R268.1
unnamed: D16.1 (K), D25.2 (A), J18.2, TP12.1
unnamed: D17.6 (L1), R71.1
unnamed: D17.4 (L2), R72.1
unnamed: C173.1, D17.5 (VP), J6.1 (VBUS), R90.2
unnamed: D18.2, R51.1
unnamed: D19.2, R55.1
unnamed: D20.2, R57.1
unnamed: D21.2, R58.1
unnamed: D22.2, R467.1
unnamed: D24.2 (A), D27.1 (K), J17.1, TP2.1
unnamed: C261.2, C263.2, C267.1, D24.1 (K), D28.1 (K), L10.1
unnamed: D26.1 (K), D28.2 (A), J17.2, TP7.1
unnamed: D29.2, R460.1
unnamed: D30.2, R461.1
unnamed: D31.2, R462.1
unnamed: J4.3 (D+), R75.1
unnamed: J4.2 (D-), R77.1
unnamed: J4.4 (ID), R74.2
unnamed: J5.11, R73.1
unnamed: J6.3 (D+), R72.2
unnamed: J6.2 (D-), R71.2
unnamed: C170.1, J6.5 (Shield), R269.1
unnamed: C120.2, J13.1, U18.16 (VDD2)
unnamed: J13.2, K1.8
unnamed: J13.3, U18.15 (B1)
unnamed: J13.4, K1.5
unnamed: J13.5, U18.14 (B2)
unnamed: J13.7, U18.13 (B3)
unnamed: J13.9, U18.12 (B4)
unnamed: J13.11, U18.11 (B5)
unnamed: J13.13, U18.10 (B6)
unnamed: J13.14, K2.8
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

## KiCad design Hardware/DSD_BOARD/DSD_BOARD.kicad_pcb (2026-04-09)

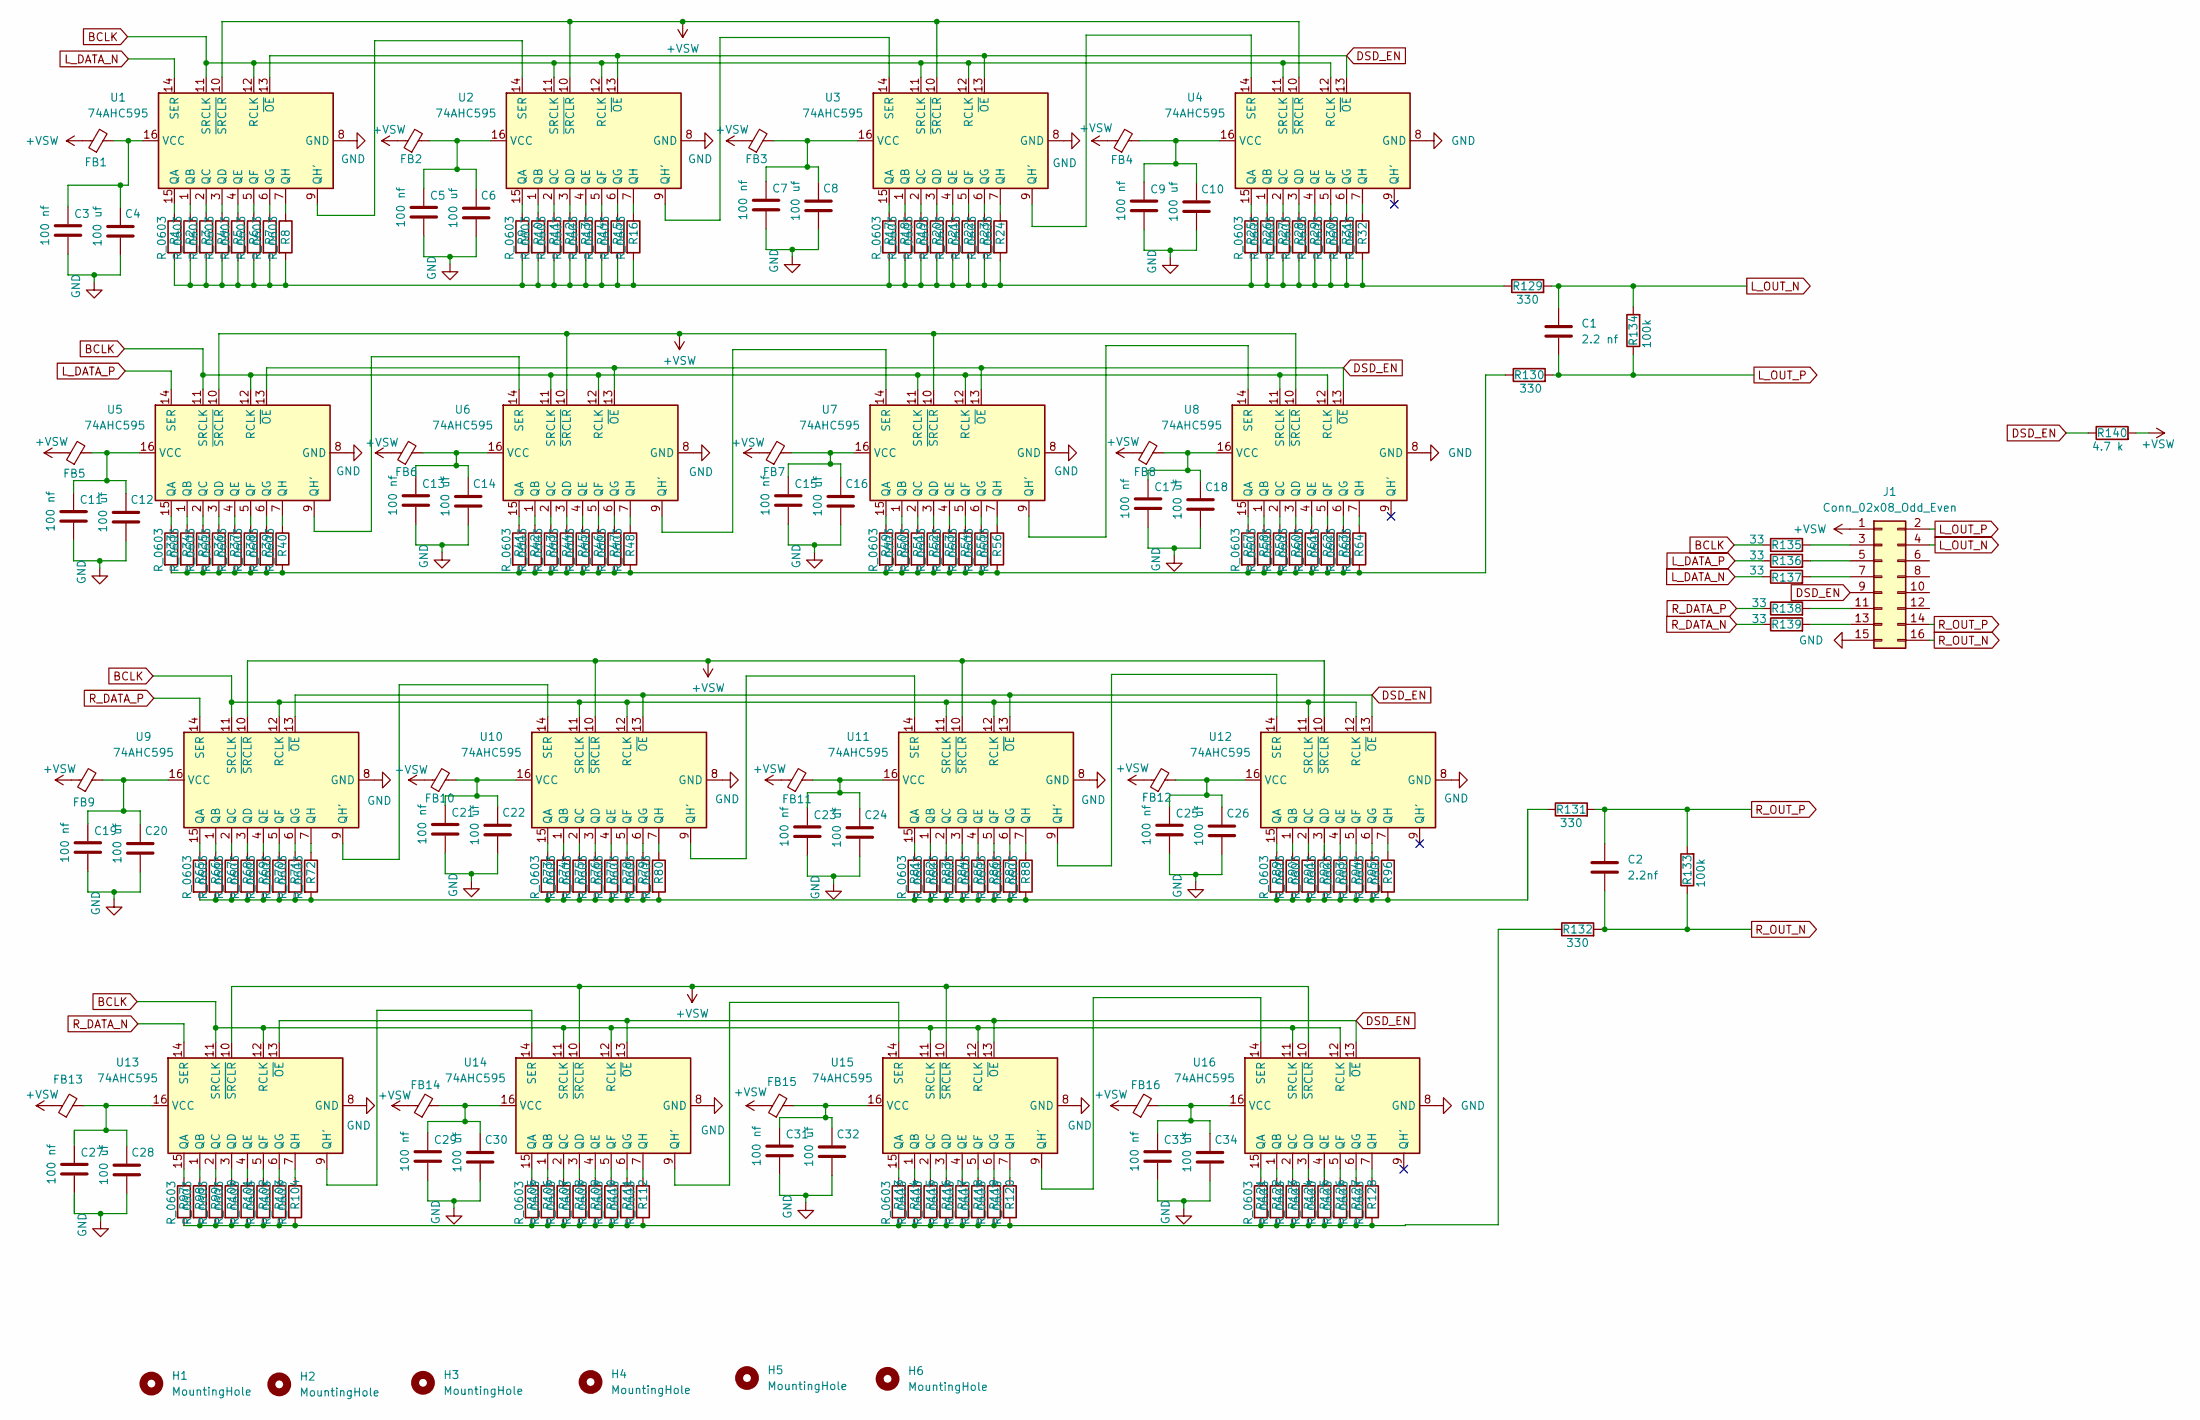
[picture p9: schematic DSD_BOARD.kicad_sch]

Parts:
C1: 2.2 nf; C_0603_1608Metric
C2: 2.2nf; C_0603_1608Metric
C3, C5, C7, C9, C11, C13, C15, C17, C19, C21, C23, C25, C27, C29, C31, C33: 100 nf; C_0603_1608Metric
C4, C6, C8, C10, C12, C14, C16, C18, C20, C22, C24, C26, C28, C30, C32, C34: 100 uf; C_1210_3225Metric_Pad1.33x2.70mm
FB1, FB2, FB3, FB4, FB5, FB6, FB7, FB8, FB9, FB10, FB11, FB12, FB13, FB14, FB15, FB16: bead; R_0603_1608Metric
H1, H2, H3, H4, H5, H6: MountingHole; MountingHole_3.2mm_M3
J1: Conn_02x08_Odd_Even; PinHeader_2x08_P2.54mm_Vertical
R1, R2, R3, R4, R5, R6, R7, R8, R9, R10, R11, R12, R13, R14, R15, R16, R17, R18, R19, R20, R21, R22, R23, R24, R25, R26, R27, R28, R29, R30, R31, R32, R33, R34, R35, R36, R37, R38, R39, R40, R41, R42, R43, R44, R45, R46, R47, R48, R49, R50, R51, R52, R53, R54, R55, R56, R57, R58, R59, R60, R61, R62, R63, R64, R65, R66, R67, R68, R69, R70, R71, R72, R73, R74, R75, R76, R77, R78, R79, R80, R81, R82, R83, R84, R85, R86, R87, R88, R89, R90, R91, R92, R93, R94, R95, R96, R97, R98, R99, R100, R101, R102, R103, R104, R105, R106, R107, R108, R109, R110, R111, R112, R113, R114, R115, R116, R117, R118, R119, R120, R121, R122, R123, R124, R125, R126, R127, R128: R_0603; R_0603_1608Metric
R129, R130, R131, R132: 330; R_0603_1608Metric
R133, R134: 100k; R_0603_1608Metric
R135, R136, R137, R138, R139: 33; R_0603_1608Metric
R140: 4.7 k; R_0603_1608Metric
U1, U2, U3, U4, U5, U6, U7, U8, U9, U10, U11, U12, U13, U14, U15, U16: 74AHC595; TSSOP-16_4.4x5mm_P0.65mm

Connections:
+VSW: FB1.1, FB2.1, FB3.1, FB4.1, FB5.1, FB6.1, FB7.1, FB8.1, FB9.1, FB10.1, FB11.1, FB12.1, FB13.1, FB14.1, FB15.1, FB16.1, J1.1, R140.2, U1.10 (~SRCLR), U2.10 (~SRCLR), U3.10 (~SRCLR), U4.10 (~SRCLR), U5.10 (~SRCLR), U6.10 (~SRCLR), U7.10 (~SRCLR), U8.10 (~SRCLR), U9.10 (~SRCLR), U10.10 (~SRCLR), U11.10 (~SRCLR), U12.10 (~SRCLR), U13.10 (~SRCLR), U14.10 (~SRCLR), U15.10 (~SRCLR), U16.10 (~SRCLR)
BCLK: R135.1, U1.11 (SRCLK), U1.12 (RCLK), U2.11 (SRCLK), U2.12 (RCLK), U3.11 (SRCLK), U3.12 (RCLK), U4.11 (SRCLK), U4.12 (RCLK), U5.11 (SRCLK), U5.12 (RCLK), U6.11 (SRCLK), U6.12 (RCLK), U7.11 (SRCLK), U7.12 (RCLK), U8.11 (SRCLK), U8.12 (RCLK), U9.11 (SRCLK), U9.12 (RCLK), U10.11 (SRCLK), U10.12 (RCLK), U11.11 (SRCLK), U11.12 (RCLK), U12.11 (SRCLK), U12.12 (RCLK), U13.11 (SRCLK), U13.12 (RCLK), U14.11 (SRCLK), U14.12 (RCLK), U15.11 (SRCLK), U15.12 (RCLK), U16.11 (SRCLK), U16.12 (RCLK)
DSD_EN: J1.9, R140.1, U1.13 (~OE), U2.13 (~OE), U3.13 (~OE), U4.13 (~OE), U5.13 (~OE), U6.13 (~OE), U7.13 (~OE), U8.13 (~OE), U9.13 (~OE), U10.13 (~OE), U11.13 (~OE), U12.13 (~OE), U13.13 (~OE), U14.13 (~OE), U15.13 (~OE), U16.13 (~OE)
GND: C3.2, C4.2, C5.2, C6.2, C7.2, C8.2, C9.2, C10.2, C11.2, C12.2, C13.2, C14.2, C15.2, C16.2, C17.2, C18.2, C19.2, C20.2, C21.2, C22.2, C23.2, C24.2, C25.2, C26.2, C27.2, C28.2, C29.2, C30.2, C31.2, C32.2, C33.2, C34.2, J1.15, U1.8 (GND), U2.8 (GND), U3.8 (GND), U4.8 (GND), U5.8 (GND), U6.8 (GND), U7.8 (GND), U8.8 (GND), U9.8 (GND), U10.8 (GND), U11.8 (GND), U12.8 (GND), U13.8 (GND), U14.8 (GND), U15.8 (GND), U16.8 (GND)
L_DATA_N: R137.1, U1.14 (SER)
L_DATA_P: R136.1, U5.14 (SER)
L_OUT_N: C1.1, J1.4, R129.2, R134.2
L_OUT_P: C1.2, J1.2, R130.2, R134.1
unnamed: J1.3, R135.2
unnamed: J1.5, R136.2
unnamed: J1.7, R137.2
unnamed: J1.11, R138.2
unnamed: J1.13, R139.2
unnamed: R1.2, R2.2, R3.2, R4.2, R5.2, R6.2, R7.2, R8.2, R9.2, R10.2, R11.2, R12.2, R13.2, R14.2, R15.2, R16.2, R17.2, R18.2, R19.2, R20.2, R21.2, R22.2, R23.2, R24.2, R25.2, R26.2, R27.2, R28.2, R29.2, R30.2, R31.2, R32.2, R129.1
unnamed: R97.2, R98.2, R99.2, R100.2, R101.2, R102.2, R103.2, R104.2, R105.2, R106.2, R107.2, R108.2, R109.2, R110.2, R111.2, R112.2, R113.2, R114.2, R115.2, R116.2, R117.2, R118.2, R119.2, R120.2, R121.2, R122.2, R123.2, R124.2, R125.2, R126.2, R127.2, R128.2, R132.1
unnamed: R33.2, R34.2, R35.2, R36.2, R37.2, R38.2, R39.2, R40.2, R41.2, R42.2, R43.2, R44.2, R45.2, R46.2, R47.2, R48.2, R49.2, R50.2, R51.2, R52.2, R53.2, R54.2, R55.2, R56.2, R57.2, R58.2, R59.2, R60.2, R61.2, R62.2, R63.2, R64.2, R130.1
unnamed: R65.2, R66.2, R67.2, R68.2, R69.2, R70.2, R71.2, R72.2, R73.2, R74.2, R75.2, R76.2, R77.2, R78.2, R79.2, R80.2, R81.2, R82.2, R83.2, R84.2, R85.2, R86.2, R87.2, R88.2, R89.2, R90.2, R91.2, R92.2, R93.2, R94.2, R95.2, R96.2, R131.1
unnamed: R1.1, U1.15 (QA)
unnamed: R2.1, U1.1 (QB)
unnamed: R3.1, U1.2 (QC)
unnamed: R4.1, U1.3 (QD)
unnamed: R5.1, U1.4 (QE)
unnamed: R6.1, U1.5 (QF)
unnamed: R7.1, U1.6 (QG)
unnamed: U1.9 (QH'), U2.14 (SER)
unnamed: R8.1, U1.7 (QH)
unnamed: C3.1, C4.1, FB1.2, U1.16 (VCC)
unnamed: R9.1, U2.15 (QA)
unnamed: R10.1, U2.1 (QB)
unnamed: R11.1, U2.2 (QC)
unnamed: R12.1, U2.3 (QD)
unnamed: R13.1, U2.4 (QE)
unnamed: R14.1, U2.5 (QF)
unnamed: R15.1, U2.6 (QG)
unnamed: U2.9 (QH'), U3.14 (SER)
unnamed: R16.1, U2.7 (QH)
unnamed: C5.1, C6.1, FB2.2, U2.16 (VCC)
unnamed: R17.1, U3.15 (QA)
unnamed: R18.1, U3.1 (QB)
unnamed: R19.1, U3.2 (QC)
unnamed: R20.1, U3.3 (QD)
unnamed: R21.1, U3.4 (QE)
unnamed: R22.1, U3.5 (QF)
unnamed: R23.1, U3.6 (QG)
unnamed: U3.9 (QH'), U4.14 (SER)
unnamed: R24.1, U3.7 (QH)
unnamed: C7.1, C8.1, FB3.2, U3.16 (VCC)
unnamed: R25.1, U4.15 (QA)
unnamed: R26.1, U4.1 (QB)
unnamed: R27.1, U4.2 (QC)
unnamed: R28.1, U4.3 (QD)
unnamed: R29.1, U4.4 (QE)
unnamed: R30.1, U4.5 (QF)
unnamed: R31.1, U4.6 (QG)
unnamed: R32.1, U4.7 (QH)
unnamed: C9.1, C10.1, FB4.2, U4.16 (VCC)
unnamed: R33.1, U5.15 (QA)
unnamed: R34.1, U5.1 (QB)
unnamed: R35.1, U5.2 (QC)
unnamed: R36.1, U5.3 (QD)
unnamed: R37.1, U5.4 (QE)
unnamed: R38.1, U5.5 (QF)
unnamed: R39.1, U5.6 (QG)
unnamed: U5.9 (QH'), U6.14 (SER)
unnamed: R40.1, U5.7 (QH)
unnamed: C11.1, C12.1, FB5.2, U5.16 (VCC)
unnamed: R41.1, U6.15 (QA)
unnamed: R42.1, U6.1 (QB)
unnamed: R43.1, U6.2 (QC)
unnamed: R44.1, U6.3 (QD)
unnamed: R45.1, U6.4 (QE)
unnamed: R46.1, U6.5 (QF)
unnamed: R47.1, U6.6 (QG)
unnamed: U6.9 (QH'), U7.14 (SER)
unnamed: R48.1, U6.7 (QH)
unnamed: C13.1, C14.1, FB6.2, U6.16 (VCC)
unnamed: R49.1, U7.15 (QA)
unnamed: R50.1, U7.1 (QB)
unnamed: R51.1, U7.2 (QC)
unnamed: R52.1, U7.3 (QD)
unnamed: R53.1, U7.4 (QE)
unnamed: R54.1, U7.5 (QF)
unnamed: R55.1, U7.6 (QG)
unnamed: U7.9 (QH'), U8.14 (SER)
unnamed: R56.1, U7.7 (QH)
unnamed: C15.1, C16.1, FB7.2, U7.16 (VCC)
unnamed: R57.1, U8.15 (QA)
unnamed: R58.1, U8.1 (QB)
unnamed: R59.1, U8.2 (QC)
unnamed: R60.1, U8.3 (QD)
unnamed: R61.1, U8.4 (QE)
unnamed: R62.1, U8.5 (QF)
unnamed: R63.1, U8.6 (QG)
unnamed: R64.1, U8.7 (QH)
unnamed: C17.1, C18.1, FB8.2, U8.16 (VCC)
unnamed: R65.1, U9.15 (QA)
unnamed: R66.1, U9.1 (QB)
unnamed: R67.1, U9.2 (QC)
unnamed: R68.1, U9.3 (QD)
unnamed: R69.1, U9.4 (QE)
unnamed: R70.1, U9.5 (QF)
unnamed: R71.1, U9.6 (QG)
unnamed: R72.1, U9.7 (QH)
unnamed: C19.1, C20.1, FB9.2, U9.16 (VCC)
unnamed: R73.1, U10.15 (QA)
unnamed: R74.1, U10.1 (QB)
unnamed: R75.1, U10.2 (QC)
unnamed: R76.1, U10.3 (QD)
unnamed: R77.1, U10.4 (QE)
unnamed: R78.1, U10.5 (QF)
unnamed: R79.1, U10.6 (QG)
unnamed: U10.9 (QH'), U11.14 (SER)
unnamed: R80.1, U10.7 (QH)
unnamed: U9.9 (QH'), U10.14 (SER)
unnamed: C21.1, C22.1, FB10.2, U10.16 (VCC)
unnamed: R81.1, U11.15 (QA)
unnamed: R82.1, U11.1 (QB)
unnamed: R83.1, U11.2 (QC)
unnamed: R84.1, U11.3 (QD)
unnamed: R85.1, U11.4 (QE)
unnamed: R86.1, U11.5 (QF)
unnamed: R87.1, U11.6 (QG)
unnamed: U11.9 (QH'), U12.14 (SER)
unnamed: R88.1, U11.7 (QH)
unnamed: C23.1, C24.1, FB11.2, U11.16 (VCC)
unnamed: R89.1, U12.15 (QA)
unnamed: R90.1, U12.1 (QB)
unnamed: R91.1, U12.2 (QC)
unnamed: R92.1, U12.3 (QD)
unnamed: R93.1, U12.4 (QE)
unnamed: R94.1, U12.5 (QF)
unnamed: R95.1, U12.6 (QG)
unnamed: R96.1, U12.7 (QH)
unnamed: C25.1, C26.1, FB12.2, U12.16 (VCC)
unnamed: R97.1, U13.15 (QA)
unnamed: R98.1, U13.1 (QB)
unnamed: R99.1, U13.2 (QC)
unnamed: R100.1, U13.3 (QD)
unnamed: R101.1, U13.4 (QE)
unnamed: R102.1, U13.5 (QF)
unnamed: R103.1, U13.6 (QG)
unnamed: U13.9 (QH'), U14.14 (SER)
unnamed: R104.1, U13.7 (QH)
unnamed: C27.1, C28.1, FB13.2, U13.16 (VCC)
unnamed: R105.1, U14.15 (QA)
unnamed: R106.1, U14.1 (QB)
unnamed: R107.1, U14.2 (QC)
unnamed: R108.1, U14.3 (QD)
unnamed: R109.1, U14.4 (QE)
unnamed: R110.1, U14.5 (QF)
unnamed: R111.1, U14.6 (QG)
unnamed: U14.9 (QH'), U15.14 (SER)
unnamed: R112.1, U14.7 (QH)
unnamed: C29.1, C30.1, FB14.2, U14.16 (VCC)
unnamed: R113.1, U15.15 (QA)
unnamed: R114.1, U15.1 (QB)
unnamed: R115.1, U15.2 (QC)
unnamed: R116.1, U15.3 (QD)
unnamed: R117.1, U15.4 (QE)
unnamed: R118.1, U15.5 (QF)
unnamed: R119.1, U15.6 (QG)
unnamed: U15.9 (QH'), U16.14 (SER)
unnamed: R120.1, U15.7 (QH)
unnamed: C31.1, C32.1, FB15.2, U15.16 (VCC)
unnamed: R121.1, U16.15 (QA)
unnamed: R122.1, U16.1 (QB)
unnamed: R123.1, U16.2 (QC)
unnamed: R124.1, U16.3 (QD)
unnamed: R125.1, U16.4 (QE)
unnamed: R126.1, U16.5 (QF)
unnamed: R127.1, U16.6 (QG)
unnamed: R128.1, U16.7 (QH)
unnamed: C33.1, C34.1, FB16.2, U16.16 (VCC)
R_DATA_N: R139.1, U13.14 (SER)
R_DATA_P: R138.1, U9.14 (SER)
R_OUT_N: C2.2, J1.16, R132.2, R133.1
R_OUT_P: C2.1, J1.14, R131.2, R133.2

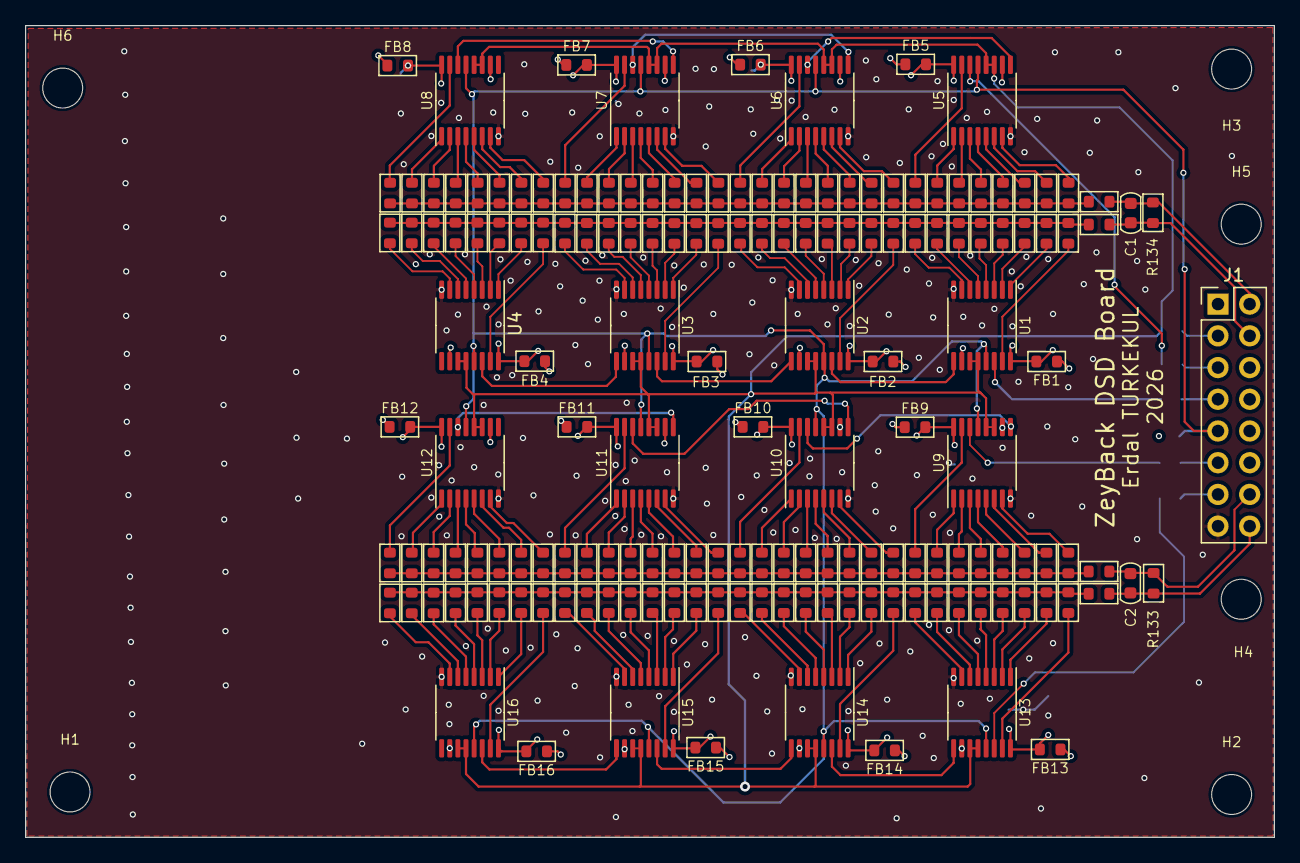
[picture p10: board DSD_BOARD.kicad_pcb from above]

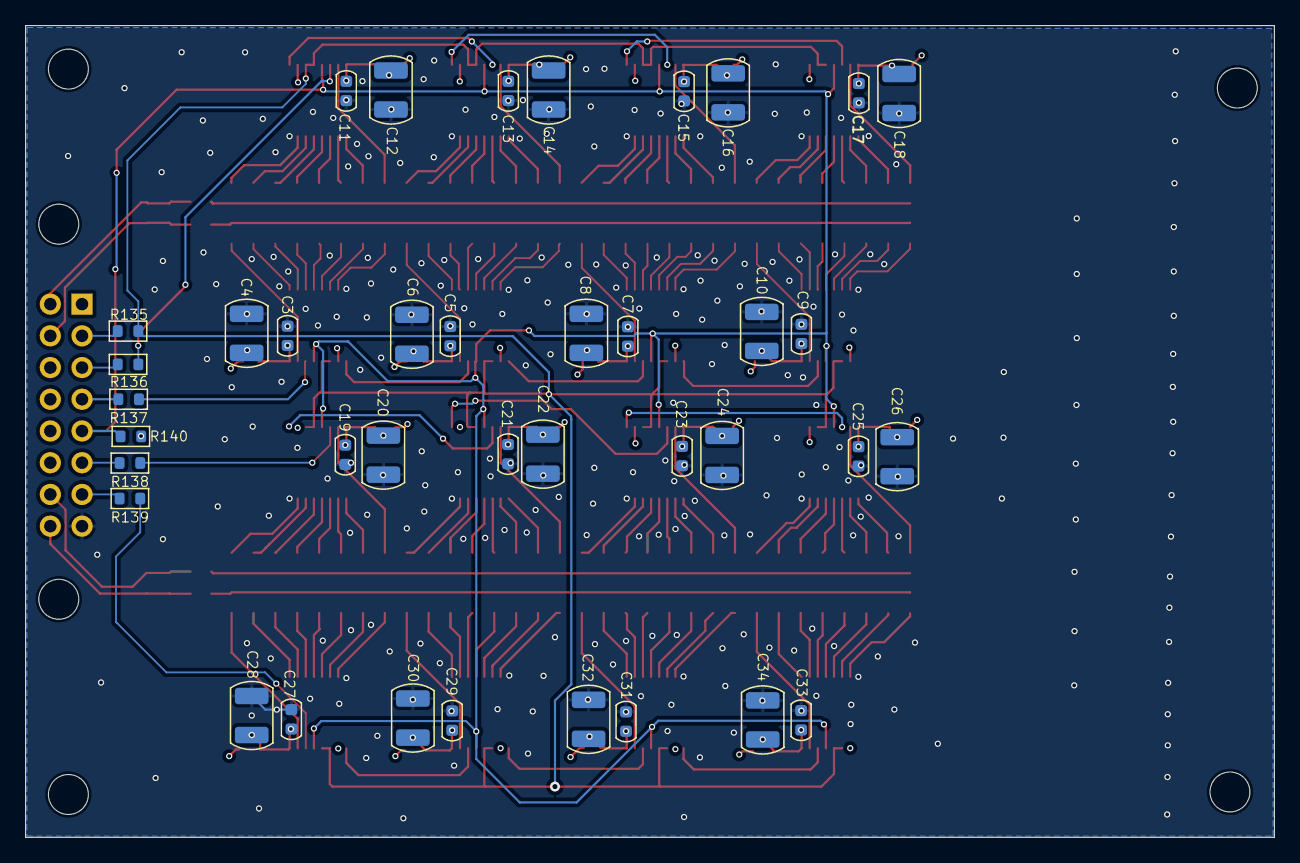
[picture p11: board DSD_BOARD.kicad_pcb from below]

Board: 4 copper layers, 100.0 x 65.0 mm, 213 parts (38 on the bottom side), 177 nets.

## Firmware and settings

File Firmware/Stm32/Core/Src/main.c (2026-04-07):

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
/* Includes ------------------------------------------------------------------*/
#include "main.h"
#include "i2c.h"
#include "memorymap.h"
#include "spi.h"
#include "tim.h"
#include "usart.h"
#include "usb_otg.h"
#include "gpio.h"
#include "fmc.h"

/* USER CODE BEGIN Includes */
#include "usb_device.h"
#include "usbd_conf.h"
#include "IRremote.h"
#include "adv7611.h"
#include "CS8416.h"
#include "SI5340.h"
#include <stdbool.h>
#include "dac_gui.h"
#include <math.h>
#include <stdint.h>
#include "audio_buffer.h"
#include "bus_poll_fpga.h"
#include <stdio.h>

/* USER CODE END Includes */

/* USER CODE BEGIN PTD */
void IR_TIM3_PeriodElapsedCallback(void); // RC5/IRremote.c’den
int SampleRate_Init_Si5340(uint32_t fs);
static   uint8_t first=1;
extern ui_state_t ui_cur;
extern uint8_t fpga_data_changed;
extern uint8_t rc5_changed;
uint32_t t_poll = 0;
static uint32_t t_dbg  = 0;
extern volatile uint32_t g_fs_pending;
extern volatile uint8_t  g_fs_apply_req;
extern volatile uint8_t  g_audio_run;
extern uint32_t g_fs_i2s;
static   uint8_t stm32_chg=0;
extern volatile uint32_t g_fpga_req_low_streak_max;
extern UART_HandleTypeDef huart4;
extern volatile int32_t  g_usb_fb_adj;   /* Adaptive feedback offset (usbd_audio.c) */
extern int SI5340_DCO_Init_N1(void);
extern int SI5340_DCO_FINC_N1(uint16_t steps);
extern int SI5340_DCO_FDEC_N1(uint16_t steps);
extern int SI5340_DCO_Recenter_N1(void);
extern int32_t SI5340_DCO_GetN1OffsetSteps(void);
static volatile uint8_t  g_fifo_resync_req = 0u; /* FIFO graceful resync isteği */
static volatile uint8_t  g_si5340_dco_ready = 0u;
/* USER CODE END PTD */


void SystemClock_Config(void);
void PeriphCommonClock_Config(void);
static void MPU_Config(void);
/* USER CODE BEGIN 0 */
void HAL_TIM_PeriodElapsedCallback(TIM_HandleTypeDef *htim)
{
    if (htim->Instance == TIM3)
    {
        IR_TIM3_PeriodElapsedCallback();
        return;
    }
}

static inline void dwt_init(void)
{
    CoreDebug->DEMCR |= CoreDebug_DEMCR_TRCENA_Msk;
    DWT->CYCCNT = 0;
    DWT->CTRL |= DWT_CTRL_CYCCNTENA_Msk;
}

static uint8_t  prev_src = 0xFF;
static uint8_t  prev_audio_on = 0x00;

static inline bool time_due(uint32_t now, uint32_t *t_next, uint32_t period_ms)
{
    if ((int32_t)(now - *t_next) >= 0) {
        *t_next += period_ms;     // drift-free pacing
        return true;
    }
    return false;
}

static inline uint8_t si5340_profile_has_dco(uint32_t fs_or_clk)
{
    /* DCO (Digital Controlled Oscillator) destekleyen profiller.
     * Kriter: Si5340_REG_N_FSTEP_MSK != 0 (ilgili .h dosyasinda 0x0339 kaydi)
     *   44.h  → 0x1D (N1 only)   88.h  → 0x1D   176.h → 0x1D
     *   352.h → 0x1F (all N)   (352800 Hz / DSD512 profili de DCO destekler)
     * PCM base rate veya dogrudan DSD clock Hz cinsinden kabul edilir.
     */
    return (fs_or_clk == 44100u   || fs_or_clk == 2822400u  ||
            fs_or_clk == 88200u   || fs_or_clk == 5644800u  ||
            fs_or_clk == 176400u  || fs_or_clk == 11289600u ||
            fs_or_clk == 352800u  || fs_or_clk == 22579200u ||
            fs_or_clk == 705600u  || fs_or_clk == 44158400u) ? 1u : 0u;
}
/* USER CODE END 0 */

/**
  * @brief  The application entry point.
  * @retval int
  */
int main(void)
{

  /* MPU Configuration--------------------------------------------------------*/
  MPU_Config();

  /* Enable the CPU Cache */

  /* Enable I-Cache---------------------------------------------------------*/
  SCB_EnableICache();

  /* Enable D-Cache---------------------------------------------------------*/
  SCB_EnableDCache();

  /* MCU Configuration--------------------------------------------------------*/

  /* Reset of all peripherals, Initializes the Flash interface and the Systick. */
  HAL_Init();

  /* USER CODE BEGIN Init */
  SCB->CCR &= ~(1u<<3);
   MX_GPIO_Init();
   LL_GPIO_ResetOutputPin(GPIOA, USB_RST_Pin);
   HAL_Delay(100);
  /* USER CODE END Init */

  /* Configure the system clock */
  SystemClock_Config();

  /* Configure the peripherals common clocks */
  PeriphCommonClock_Config();

  /* USER CODE BEGIN SysInit */
  LL_GPIO_SetOutputPin(GPIOI, RST_SI_Pin);

   LL_GPIO_ResetOutputPin(GPIOA, USB_RST_Pin);
   LL_GPIO_ResetOutputPin(GPIOI, HDMI_RESET_Pin);

   HAL_Delay(30);
   LL_GPIO_SetOutputPin(GPIOA, USB_RST_Pin);
   LL_GPIO_SetOutputPin(GPIOI, HDMI_RESET_Pin);

   HAL_Delay(30);
  /* USER CODE END SysInit */

  /* Initialize all configured peripherals */
  MX_GPIO_Init();
  MX_FMC_Init();
  MX_I2C1_Init();
  MX_SPI2_Init();
  MX_SPI4_Init();
  MX_TIM3_Init();
  MX_USB_OTG_HS_PCD_Init();
  MX_UART4_Init();
  MX_TIM2_Init();
  /* USER CODE BEGIN 2 */
  my_enableIRIn();
     MX_USB_DEVICE_Init();




            // LL_GPIO_ResetOutputPin(GPIOC, DSP_Pin);
            // LL_GPIO_ResetOutputPin(GPIOC, RCLK_ON_Pin);
             LL_GPIO_ResetOutputPin(GPIOC, RSTB_Pin);
             HAL_Delay(1);
             App_Init_Si5340();



             if ( ADV7611_Init()==0){
                	  while(1);
                  }



             EDID_Conf();
             CS8416_Init();

             dwt_init();
             //CS8416_SetOutputFormat_I2S();

            // bus_dma_tim1_init(240000000u);
             SampleRate_Init_Si5340(44100);
           //  bus_dma_tim1_set_fs(44100u);

             LL_GPIO_ResetOutputPin(MUTE_GPIO_Port, MUTE_Pin);
            // bus_dma_tim1_start();
             //static uint32_t t0 = 0;

             AudioBuffer_Init(AudioBuffer_Instance(), 0);  /* ring buffer sıfırla */
                bus_poll_init();
                fpga_set_stream_en(0);                        /* başlangıçta stream kapalı */
                SampleRate_Init_Si5340(44100u);
                g_si5340_dco_ready = si5340_profile_has_dco(44100u);
                if (g_si5340_dco_ready) {
                    SI5340_DCO_Init_N1();
                    SI5340_DCO_Recenter_N1();
                }
            // static uint32_t g_fs_pending_old = 44100;
  /* USER CODE END 2 */

  /* Infinite loop */
  /* USER CODE BEGIN WHILE */
                while (1)
                                {

                          	  // debug_audio_print_once(&huart4, 2000);

                          	     uint32_t now = HAL_GetTick();

                                    /* ----------------------------------------------------
                                     * 1. Stream aktif mi?
                                     *    g_audio_run: USB ISO OUT başladığında UAC2 stack set eder.
                                     *    ui_cur.src == SRC_STM32: kullanıcı USB kaynağını seçmiş.
                                     * ---------------------------------------------------- */
                                    uint8_t audio_on = (g_audio_run && (ui_cur.src == SRC_STM32)) ? 1u : 0u;


                                    /* ----------------------------------------------------
                                     * 2. Stream durum geçişi
                                     * ---------------------------------------------------- */
                                    if (audio_on != prev_audio_on || ui_cur.src != prev_src)
                                    {
                                        prev_audio_on = audio_on;
                                        prev_src      = ui_cur.src;

                                        if (audio_on)
                                        {
                                            /* Stream başladı:
                                             *   a) MUTE: pre-fill tamamlanana kadar ses kesilir
                                             *   b) RESYNC: FPGA'daki kısmi L/R çiftini sil
                                             *   c) EN_STREAM yükselt: FPGA FIFO'yu flush eder (~640ns)
                                             *   d) FIFO ön doldurma: FPGA FIFO prog_empty (4096)
                                             *      eşiğini aşacak kadar veri birikmesini bekle.
                                             *      Beklenmezse FIFO bos baslar, her USB timing
                                             *      sapmasi FIFO'yu bosaltir → citirtilar.
                                             */
                                            LL_GPIO_SetOutputPin(MUTE_GPIO_Port, MUTE_Pin);
                                            HAL_Delay(3); /* Mute devresinin kapanmasini bekle */
                                            fpga_send_resync();
                                            fpga_set_stream_en(1);   /* AudioBuffer sifirla, s_running=1 */
                                            if (g_si5340_dco_ready) {
                                                SI5340_DCO_Recenter_N1();
                                            }

                                            /* AudioBuffer'in ~131072 byte birikmesini bekle */
                                            {
                                                uint32_t t0 = HAL_GetTick();
                                                while (AudioBuffer_LevelBytes(AudioBuffer_Instance()) < 131072u) {
                                                    if ((uint32_t)(HAL_GetTick() - t0) > 300u) break;
                                                }
                                            }
                                            /* FIFO'ya hizla ~8192 entry yaz (prog_empty esigini bol as) */
                                            bus_poll_service(8192u);
                                            HAL_Delay(5); /* FIFO cikisinin stabilize olmasini bekle */
                                            LL_GPIO_ResetOutputPin(MUTE_GPIO_Port, MUTE_Pin);
                                        }
                                        else
                                        {
                                            /* Stream durdu: once MUTE, sonra FPGA durdur
                                             * (ters sirada FPGA dururken ses yolu acik → pop) */
                                            LL_GPIO_SetOutputPin(MUTE_GPIO_Port, MUTE_Pin);
                                            HAL_Delay(3);
                                            fpga_set_stream_en(0);
                                        }

                                        apply_input_select(ui_cur.src);
                                    }

                                    /* ----------------------------------------------------
                                     * 3. Polling transfer — sadece stream aktifken
                                     *
                                     *    max_frames = 128:
                                     *      44.1kHz → 44 frame/ms → 128 frame ≈ 2.9ms
                                     *      384kHz  → 384 frame/ms → 128 frame ≈ 0.33ms
                                     *    Ana döngü her turda çağrılır; underrun olursa
                                     *    istatistikte görünür, ses kesilmez (FIFO zero-hold).
                                     * ---------------------------------------------------- */
                                    if (audio_on)
                                    {
                                        bus_poll_service(512u);
                                    }

                                    /* ----------------------------------------------------
                                     * 3b. Graceful FIFO Resync
                                     *
                                     * FPGA FIFO saat kaymasindan dolayi prog_empty'e
                                     * duserse ve USB adaptive feedback cevap vermezse,
                                     * crackling yerine ~25ms sessizlik ile FIFO yeniden
                                     * doldurulur. Akis: MUTE → FIFO flush → AudioBuffer
                                     * doldur → FIFO on-doldur → UNMUTE.
                                     *
                                     * DSD256: 131072 byte / 5.644MB/s = ~23ms doldurma
                                     * DSD64:  131072 byte / 1.411MB/s = ~93ms doldurma
                                     * ---------------------------------------------------- */
                                    if (audio_on && g_fifo_resync_req)
                                    {
                                        g_fifo_resync_req = 0u;
                                        g_usb_fb_adj      = 0;   /* adj sifirla: temiz baslangic */

                                        LL_GPIO_SetOutputPin(MUTE_GPIO_Port, MUTE_Pin); /* sus */
                                        HAL_Delay(3); /* Mute devresinin kapanmasini bekle */
                                        fpga_send_resync();
                                        if (g_si5340_dco_ready) {
                                            SI5340_DCO_Recenter_N1();
                                        }
                                        //fpga_set_stream_en(1);   /* AudioBuffer & FIFO sifirla */

                                        {
                                            uint32_t t0 = HAL_GetTick();
                                            while (AudioBuffer_LevelBytes(AudioBuffer_Instance()) < 131072u) {
                                                if ((uint32_t)(HAL_GetTick() - t0) > 400u) break;
                                            }
                                        }
                                        bus_poll_service(32768u); /* FIFO on-doldur */
                                        HAL_Delay(5); /* FIFO cikisinin stabilize olmasini bekle */
                                        LL_GPIO_ResetOutputPin(MUTE_GPIO_Port, MUTE_Pin); /* ses ac */
                                    }

                                    /* ----------------------------------------------------
                                     * 4. Sample rate değişimi
                                     *
                                     * PCM→DSD256 geçişinde iki ardışık rate değişimi olur:
                                     *   a) EP0_RxReady: g_fs_pending = DoP taşıyıcı (ör. 705600)
                                     *   b) enter_dop_mode_runtime() (USB ISR, 131072 byte bekleme
                                     *      sırasında): g_fs_pending = Si5340 frekansı (ör. 176400)
                                     *      ve aynı anda FPGA DSD moduna alınır.
                                     *
                                     * BUG (düzeltildi): Eski kodda (a) sonrası UNMUTE yapılıyor,
                                     * FPGA DSD modundayken Si5340 hâlâ yanlış frekansta → kare dalga.
                                     *
                                     * FIX: do...while(g_fs_apply_req) döngüsü — DoP tespiti
                                     * yeni bir g_fs_apply_req tetiklerse MUTE korunarak (b) de
                                     * uygulanır; UNMUTE yalnızca rate kararlı olduktan sonra yapılır.
                                     * ---------------------------------------------------- */
                                    if (audio_on && (g_fs_apply_req || stm32_chg))
                                    {
                                        LL_GPIO_SetOutputPin(MUTE_GPIO_Port, MUTE_Pin);   /* ses kes */
                                        HAL_Delay(10);

                                        do {
                                            /* --------------------------------------------------
                                             * ÖNCE temizle: SampleRate_Init_Si5340() içindeki
                                             * HAL_Delay(300) sırasında USB ISR enter_dop_mode_runtime()
                                             * çağırıp g_fs_apply_req=1 set edebilir.
                                             * Temizleme SONRAYA bırakılırsa ISR'nin set ettiği değer
                                             * hemen ezilir → do...while erken çıkar → UNMUTE yanlış
                                             * Si5340 frekansıyla yapılır → kare dalga.
                                             * Başa alınınca: ISR yeni rate'i set ederse döngü bir tur
                                             * daha döner ve g_fs_pending ile Si5340 yeniden yüklenir.
                                             * -------------------------------------------------- */
                                            g_fs_apply_req = 0u;
                                            stm32_chg      = 0u;
                                            g_usb_fb_adj   = 0;   /* Yeni sample rate, offset sifirla */

                                            AudioBuffer_Init(AudioBuffer_Instance(), 0);      /* ring sıfırla */
                                            SampleRate_Init_Si5340(g_fs_pending);             /* SI5340 (~315ms: 300ms HAL_Delay + lock) */
                                            g_si5340_dco_ready = si5340_profile_has_dco(g_fs_pending);
                                            if (g_si5340_dco_ready) {
                                                SI5340_DCO_Init_N1();
                                                SI5340_DCO_Recenter_N1();
                                            }
                                            fpga_send_resync();                               /* kısmi L/R temizle */
                                            fpga_set_stream_en(1);                            /* stream aç, s_running=1 */

                                            /* --------------------------------------------------
                                             * FIFO Ön Doldurma:
                                             * Bu bekleme sırasında USB ISR çalışır; DoP tespit
                                             * edilirse enter_dop_mode_runtime() g_fs_apply_req'u
                                             * tekrar set eder → döngü bir tur daha döner.
                                             * -------------------------------------------------- */
                                            {
                                                uint32_t t0 = HAL_GetTick();
                                                while (AudioBuffer_LevelBytes(AudioBuffer_Instance()) < 131072u) {
                                                    if ((uint32_t)(HAL_GetTick() - t0) > 300u) break;
                                                }
                                            }

                                        } while (g_fs_apply_req); /* DoP ikinci rate geçişi: MUTE korunarak uygula */

                                        /* FIFO'ya hizla ~8192 entry yaz (prog_empty eşiğini (~4096) bol aş) */
                                        bus_poll_service(32768u);

                                        HAL_Delay(15);
                                        LL_GPIO_ResetOutputPin(MUTE_GPIO_Port, MUTE_Pin); /* sesi aç */
                                    }

                                    /* ----------------------------------------------------
                                     * 5. Debug: stats + FPGA durum (2000ms)
                                     * ---------------------------------------------------- */
                                    if (g_dsd_mode != DSD_MODE_OFF && si5340_profile_has_dco(g_dsd_clock_hz)) {
                                    if (time_due(now, &t_dbg, 2000u) && audio_on)
                                    {
                                        /* Static buffer: HAL_UART_Transmit_IT async calisir,
                                         * stack frame cokmeleri onlemek icin static kullan. */
                                        static char dbg_buf[128];
                                        fpga_stats_t dbg = fpga_get_stats();
                                        uint32_t fpga_st = fpga_read_status();
                                        uint32_t ab_lvl  = AudioBuffer_LevelBytes(AudioBuffer_Instance());
                                        int32_t dco_off = SI5340_DCO_GetN1OffsetSteps();
                                        int  len = snprintf(dbg_buf, sizeof(dbg_buf),
                                            "under=%lu ovfl=%lu fr=%lu ab=%lu fpga=0x%02lX dco=%ld rs=%lu\r\n",
                                            (unsigned long)dbg.underruns,
                                            (unsigned long)dbg.overflows,
                                            (unsigned long)dbg.frames_sent,
                                            (unsigned long)ab_lvl,
                                            (unsigned long)(fpga_st & 0xFFu),
                                            (long)dco_off,
                                            (unsigned long)dbg.resync_count);
                                        HAL_UART_Transmit(&huart4, (uint8_t*)dbg_buf, (uint16_t)len, 10u);
                                        fpga_reset_stats();
                                    }

                                    /* ----------------------------------------------------
                                     * 6. FPGA durum sorgusu + adaptive feedback (200ms)
                                     * ---------------------------------------------------- */

                                    if (time_due(now, &t_poll, 20u))
                                    {
                                        poll_fpga_data();
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

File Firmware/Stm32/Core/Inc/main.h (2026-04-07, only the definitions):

#define CSB_SI_Pin LL_GPIO_PIN_5
#define CSB_SI_GPIO_Port GPIOI
#define HDMI_RESET_Pin LL_GPIO_PIN_4
#define HDMI_RESET_GPIO_Port GPIOI
#define DSD_EN_Pin LL_GPIO_PIN_3
#define DSD_EN_GPIO_Port GPIOD
#define RSTB_Pin LL_GPIO_PIN_15
#define RSTB_GPIO_Port GPIOC
#define CS8416_CSB_Pin LL_GPIO_PIN_4
#define CS8416_CSB_GPIO_Port GPIOE
#define DSP_Pin LL_GPIO_PIN_2
#define DSP_GPIO_Port GPIOD
#define RST_SI_Pin LL_GPIO_PIN_10
#define RST_SI_GPIO_Port GPIOA
#define STM32_SYNC_Pin LL_GPIO_PIN_9
#define STM32_SYNC_GPIO_Port GPIOA
#define STM32_EN_Pin LL_GPIO_PIN_8
#define STM32_EN_GPIO_Port GPIOC
#define STM32_REQ_Pin LL_GPIO_PIN_9
#define STM32_REQ_GPIO_Port GPIOC
#define OLED_CLK_Pin LL_GPIO_PIN_12
#define OLED_CLK_GPIO_Port GPIOA
#define MUTE_Pin LL_GPIO_PIN_7
#define MUTE_GPIO_Port GPIOG
#define SEL3_Pin LL_GPIO_PIN_5
#define SEL3_GPIO_Port GPIOG
#define RCLK_ON_Pin LL_GPIO_PIN_6
#define RCLK_ON_GPIO_Port GPIOG
#define SEL2_Pin LL_GPIO_PIN_4
#define SEL2_GPIO_Port GPIOG
#define SEL1_Pin LL_GPIO_PIN_3
#define SEL1_GPIO_Port GPIOG
#define SEL0_Pin LL_GPIO_PIN_2
#define SEL0_GPIO_Port GPIOG
#define SR2_Pin LL_GPIO_PIN_2
#define SR2_GPIO_Port GPIOK
#define SR0_Pin LL_GPIO_PIN_0
#define SR0_GPIO_Port GPIOK
#define SR1_Pin LL_GPIO_PIN_1
#define SR1_GPIO_Port GPIOK
#define SR3_Pin LL_GPIO_PIN_11
#define SR3_GPIO_Port GPIOJ
#define BitRate_Pin LL_GPIO_PIN_10
#define BitRate_GPIO_Port GPIOJ
#define LED2_Pin LL_GPIO_PIN_1
#define LED2_GPIO_Port GPIOA
#define USB_RST_Pin LL_GPIO_PIN_0
#define USB_RST_GPIO_Port GPIOA
#define IR_Pin LL_GPIO_PIN_15
#define IR_GPIO_Port GPIOF
#define LED3_Pin LL_GPIO_PIN_4
#define LED3_GPIO_Port GPIOC
#define OLED_RST_Pin LL_GPIO_PIN_6
#define OLED_RST_GPIO_Port GPIOH
#define OLED_DATA_Pin LL_GPIO_PIN_15
#define OLED_DATA_GPIO_Port GPIOB
#define LED1_Pin LL_GPIO_PIN_4
#define LED1_GPIO_Port GPIOA
#define LED4_Pin LL_GPIO_PIN_5
#define LED4_GPIO_Port GPIOC
#define OLED_DC_Pin LL_GPIO_PIN_7
#define OLED_DC_GPIO_Port GPIOH
#define OLED_CS_Pin LL_GPIO_PIN_14
#define OLED_CS_GPIO_Port GPIOB

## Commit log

2026-01-10 Add firmware and hardware
    [ANALOG.kicad_sch, ARTIX7.kicad_sch, FPGA.kicad_sch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]
2026-04-07 DSD board added
    Added DSD board
    [DSD_BOARD.kicad_pcb, DSD_BOARD.kicad_sch]
2026-04-08 remove unused files
    [PINLER.xlsx]
2026-04-09 DSD Board Rev
    [DSD_BOARD.kicad_pcb, DSD_BOARD.kicad_sch]
2026-04-09 Changing Hardware file structure
    [ANALOG.kicad_sch, ARTIX7.kicad_sch, FPGA.kicad_sch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]
2026-04-19 Fixed DSD play
    Fixed DSD play FPGA cross connection and XMOS and STM32H750 DSD Play
2026-04-19 some PCB/schemtic improvements
    some PCB improvements,
    three additional debug LEDs,
    add serial res. at data/clk line
    [ANALOG.kicad_sch, ARTIX7.kicad_sch, FPGA.kicad_sch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]
2026-04-19 DAC Source Sellect Bug Fixed
    [dac_gui.c, dac_gui.h]

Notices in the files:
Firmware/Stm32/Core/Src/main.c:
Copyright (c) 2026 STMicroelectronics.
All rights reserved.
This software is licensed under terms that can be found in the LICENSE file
